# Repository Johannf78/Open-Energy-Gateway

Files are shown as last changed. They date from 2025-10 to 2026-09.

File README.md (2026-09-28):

# AmpX Open Energy Gateway





A comprehensive ESP32-based energy monitoring gateway that communicates with Meatrol Brand energy meters via Modbus protocols (RS485 and TCP/IP). The system collects data from up to 32 meters simultaneously, displays it through a web interface, and uploads measurements to a remote API for centralized monitoring.

**Buy ready-built hardware:** <a href="https://ampx.co/product/ampx-energy-gateway/" target="_blank" rel="noopener noreferrer">AmpX Energy Gateway</a> on ampx.co — DIN-rail unit with WiFi, RS485 or TCP/IP Modbus, and uploads to <a href="https://ampx.app" target="_blank" rel="noopener noreferrer">ampx.app</a>.

## 🌟 Features

### Core Capabilities
- **Multi-Protocol Support**: Compatible with both Modbus RS485 and Modbus TCP/IP communication
- **Multi-Meter Support**: Monitor up to 32 energy meters simultaneously
- **Real-Time Web Interface**: Live data display with WebSocket updates
- **API Integration**: Automatic data upload to AmpX Portal every 30 seconds
- **Auto-Discovery**: Automatic detection of connected meters
- **Dual Hardware Variants**: Separate builds for RS485 and TCP/IP configurations

### Hardware Integration
- **ESP32 Wroom 32U**: Main microcontroller platform
- **RS485 Interface**: MAX485 module for serial communication
- **Ethernet Interface**: W5500 Lite for TCP/IP communication
- **Status Indicators**: Four LEDs for system status monitoring
- **WiFi Support**: Wireless connectivity with WiFiManager

### Data Management
- **Real-Time Monitoring**: 3-second update intervals for web interface
- **Scheduled Uploads**: 30-second intervals for API data transmission
- **JSON Data Format**: Structured data exchange and storage
- **Meter Identification**: Unique serial number tracking for each meter

## ☁️ AmpX Energy Portal

View gateway and meter data in the cloud at <a href="https://ampx.app/" target="_blank" rel="noopener noreferrer">https://ampx.app/</a>.

The portal lets you manage gateways, inspect live and historical readings (voltage, current, power, and energy per phase), and export CSV for reporting. The firmware uploads a timestamped snapshot about every 30 seconds.

The portal can be **white-labelled** for your company or resellers (your branding, your domain). Data can also be **customised** and sent to **any portal or platform**, in **any format** you require. Contact AmpX if you need a branded instance or a custom integration.

## 🏗️ Architecture

```
┌─────────────────┐    ┌──────────────────┐    ┌─────────────────┐
│   Energy Meters │    │  AmpX Gateway    │    │   AmpX Portal   │
│                 │    │                  │    │                 │
│ Meatrol Meters  │◄──►│ ESP32 + Modbus   │◄──►│ Remote API      │
│ (RS485/TCP-IP)  │    │ Web Interface    │    │ Data Storage    │
│ Up to 32 units  │    │ Data Processing  │    │ Analytics       │
└─────────────────┘    └──────────────────┘    └─────────────────┘
```

## 📋 Hardware Requirements

### Base Components
- **ESP32 Wroom 32U** microcontroller
- **Power Supply**: 3.3V regulated power
- **Status LEDs**: 5x LEDs for system monitoring (Power, Meter, WiFi, Internet, Server)

### RS485 Configuration
- **MAX485 Interface Module**
- **RS485 Cable**: For meter communication
- **Pull-up/Pull-down Resistors**: 120Ω termination resistors

### TCP/IP Configuration
- **W5500 Lite Ethernet Module**
- **Ethernet Cable**: CAT5/CAT6 network connection
- **Network Switch/Router**: For meter and internet connectivity

## 🚀 Installation

### Prerequisites
- [Arduino IDE](https://www.arduino.cc/en/software) (recommended)
- In Arduino IDE, add this under `File -> Preferences -> Additional Board Manager URLs`:  
  `https://raw.githubusercontent.com/espressif/arduino-esp32/gh-pages/package_esp32_index.json`
  Then install `esp32` from `Tools -> Board -> Boards Manager`.
- ESP32 Board Package for Arduino IDE
- USB-to-UART driver for your ESP32 board (CP210x VCP driver): [Silicon Labs CP210x USB to UART Bridge VCP Drivers](https://www.silabs.com/developers/usb-to-uart-bridge-vcp-drivers)
- Required Arduino libraries (see Dependencies section)

### Quick Start

1. **Clone the Repository**
   ```bash
   git clone https://github.com/Johannf78/Open-Energy-Gateway.git
   cd Open-Energy-Gateway
   ```

2. **Open the Project**
   - **Arduino IDE** (recommended): Open `src/open_energy_gateway/open_energy_gateway.ino`
   - Alternative - PlatformIO: Open the project folder

3. **Configure Hardware Type**
   
   In `open_energy_gateway.ino`, set the communication type:
   ```cpp
   #define MODBUS_TYPE MODBUS_TYPE_RS485  // For RS485 version
   // OR
   #define MODBUS_TYPE MODBUS_TYPE_TCPIP  // For TCP/IP version
   ```

4. **Install USB Driver (Required)**
   - Most ESP32 development boards use a CP210x USB-to-UART bridge chip
   - Install the CP210x VCP driver from Silicon Labs:  
     [https://www.silabs.com/developers/usb-to-uart-bridge-vcp-drivers](https://www.silabs.com/developers/usb-to-uart-bridge-vcp-drivers)
   - On the Silicon Labs download list (Windows), select **CP210x Windows Drivers**
   - Reconnect the board after driver installation so the serial COM port is detected

5. **Upload to ESP32**
   - Connect your ESP32 via USB
   - Select the correct board and port
   - Compile and upload the code

### Dependencies

The following libraries are required:
```cpp
#include <WiFi.h>              // ESP32 built-in WiFi
#include <WebServer.h>         // ESP32 built-in web server
#include <WebSocketsServer.h>  // Real-time updates (by Markus Sattler)
#include <ArduinoJson.h>       // JSON processing (by Benoit Blanchon)
#include <HTTPClient.h>        // ESP32 built-in HTTP client
#include <WiFiManager.h>       // WiFi configuration (by tzapu)
#include <Preferences.h>       // ESP32 built-in NVS storage
#include <HardwareSerial.h>    // ESP32 built-in serial communication
#include <time.h>              // ESP32 built-in time functions
```

### Custom Libraries (Required)
The project requires custom AmpX Modbus libraries available at:
**Repository**: [https://github.com/Johannf78/AmpXModbus](https://github.com/Johannf78/AmpXModbus)

- **For RS485**: `ampx_modbus_rs485.h` 
- **For TCP/IP**: `ampx_modbus_tcpip.h`

**Installation**:
1. Clone or download the AmpXModbus repository
2. Copy the library folders to your Arduino libraries directory:
   `Documents/Arduino/libraries/`

## 🔧 Configuration

### WiFi Setup
On first boot, the device creates a WiFi access point:
- **SSID**: `AmpX-Energy-Gateway-AP`
- **Password**: None (open network)
- Connect and configure your WiFi credentials through the captive portal

### Meter Configuration
Meters are automatically discovered during startup. The system supports:
- **Meter Addresses**: 1-32 (configurable)
- **Baud Rate**: 9600 (RS485)
- **Data Bits**: 8
- **Parity**: None
- **Stop Bits**: 1

### API Configuration
The system supports dual API endpoints (configurable in `open_energy_gateway.ino`):
```cpp
// Local: LAN IP of the PC running XAMPP (port 80). Update when the PC IP changes.
const char* ampxportal_server_local = "http://192.168.2.120/api/v3/";
const char* ampxportal_server_live = "https://ampx.app/api/v3/";
const char* ampxportal_api_key = "...";  // must match AMPX_API_KEY in api/config/config.php
#define USE_LOCAL_SERVER false  // true = LAN XAMPP /api/v3/; false = live /api/v3/
```

Every upload sends header `X-AmpX-Api-Key` (firmware **1.0.3+**). Full API docs: `ampx.app/api/README.md`.

**Breaking changes:** If the portal/API contract changes so older flashed gateways fail, bump `FIRMWARE_VERSION` in the same change and publish OTA before (or with) the live API cutover. The API key requirement is one such break (pre-1.0.3 → 401).

**Local development stack (verified July–August 2026):**
- API: XAMPP at `D:\xampp\htdocs\ampx.app\api\` — firmware posts `POST /api/v3/` (Cloud). Header `X-AmpX-Api-Key` (see that folder’s `README.md`)
- Portal UI: http://ampx-app.local/ (WordPress vhost; not the public Cloudflare `ampx.app` host)
- InfluxDB (legacy v2 path): `influxdb2.ampx.app` via `POST /api/v2/`
- InfluxDB (portal + v3): managed **Cloud Serverless** — account AmpX / org **Energy Gateway** — host `https://eu-central-1-1.aws.cloud2.influxdata.com` (AWS Frankfurt); see `ampx.app/api/README.md`
- Postman: `http://ampx-app.local/api/v2/` or `http://127.0.0.1/api/v2/` — enable header `X-AmpX-Api-Key`
- ESP must reach the PC on TCP **80**; Windows Wi‑Fi profile should be **Private** with Apache firewall allow rules
- Do not use port **8080** unless a separate Docker API is running

**Live stack (verified August 2026 Cloud cutover):**
- API: `https://ampx.app/api/v3/` — `#define USE_LOCAL_SERVER false` (v2 still on Influx 2 until sunset)
- Portal UI: https://ampx.app/ → Meters → gateway → View Data (Cloud / InfluxQL, plugin 1.1.5)
- WordPress `wp-config.php` `AMPX_INFLUXDB_*` → Cloud Serverless; **ORG** = `Energy Gateway` (not AmpX)
- After editing live `wp-config.php` on Hetzner: flush PHP OPcache
- Create/assign the gateway in WP Admin; Influx data alone does not register it in the portal list
- OTA: live `version.json` is **1.0.9** (v2). Next publish is **1.1.1**. Do not publish 1.0.9.

## 💻 Usage

### Web Interface
1. Connect to your local network
2. Find the ESP32's IP address (displayed on serial monitor)
3. Open `http://[ESP32_IP_ADDRESS]` in your browser
4. View real-time meter data in tabular format

### Data Format
The system collects and transmits:
- **Meter Serial Numbers**: Unique identification
- **Energy Measurements**: kWh, kW, Voltage, Current
- **Timestamps**: Measurement time
- **Status Information**: Connection and error states

### API Integration
Data is automatically uploaded to the AmpX Portal every 30 seconds in JSON format:
```json
{
  "gateway_id": "100001",
  "meter_id": "1",
  "serial_number": "12345678",
  "timestamp": "2024-01-15T10:30:00Z",
  "values": {
    "serial": "12345678",
    "voltage_L1": "230.1",
    "current_L1": "24.6",
    "active_power_tot": "5.67",
    "active_energy_imported_tot": "1234.56"
  }
}
```

## 🛠️ Development

### Project Structure
```
Open-Energy-Gateway/
├── src/
│   └── open_energy_gateway/
│       ├── open_energy_gateway.ino       # Main application
│       ├── functions.ino                 # NVS utilities
│       ├── functions_modbus.ino          # Modbus communication
│       ├── functions_web.ino             # Web interface & WebSocket
│       ├── functions_wifi.ino            # WiFi management
│       ├── functions_ethernet.ino        # Ethernet initialization
│       ├── functions_meter.ino           # Meter register definitions
│       ├── functions_api.ino             # API communication
│       ├── functions_ntp.ino             # Time synchronization
│       ├── functions_ota.ino             # HTTP pull OTA (Admin)
│       ├── meter_registers.h             # Register definitions
│       ├── webpage.h                     # HTML templates
│       ├── web_admin.h                   # Admin interface
│       ├── web_settings.h                # Settings page
│       ├── data/                         # Web assets (future SPIFFS option)
│       │   ├── index.html
│       │   ├── settings.html
│       │   ├── admin.html
│       │   └── meter_registers_meatrol.json
│       └── tools/                        # SPIFFS tools (future use)
│           ├── create_spiffs.bat
│           ├── upload_spiffs.bat
│           └── spiffsgen.py
├── memory-bank/                          # Project documentation
├── Documentation/                        # User documentation
└── README.md
```

### Building Different Variants
- **RS485 Version**: Set `MODBUS_TYPE_RS485`
- **TCP/IP Version**: Set `MODBUS_TYPE_TCPIP`

### Debugging
Enable debug output by defining:
```cpp
#define DEBUG 1
```

### Web Interface Implementation
Currently, the web interface is implemented using header files containing HTML templates:

- **webpage.h**: Main dashboard HTML template
- **web_settings.h**: Settings page HTML template  
- **web_admin.h**: Admin page HTML template

The templates use string replacement for dynamic content (meter serial numbers, values, etc.).

### Future SPIFFS Option
The project includes infrastructure for future SPIFFS implementation:

1. **SPIFFS Tools Available** (not currently used):
   ```bash
   cd src/open_energy_gateway/tools
   create_spiffs.bat  # Future: Create SPIFFS image
   upload_spiffs.bat  # Future: Upload to ESP32
   ```

2. **Web Assets Ready** in `data/` folder for future SPIFFS deployment

### Current Limitations
- **Active Meters**: Currently configured for 5 meters (backend expandable; HTML rows needed beyond that)
- **Server URLs**: API and OTA hosts (`ampxportal_server_local` / `_live`, `USE_LOCAL_SERVER`, firmware URLs) require a firmware rebuild
- **Gateway ID**: Changeable from Admin; stored in NVS (`DEFAULT_GATEWAY_ID` is first-boot only)
- **OTA Updates**: Admin HTTP pull from `https://ampx.app/firmware/` (Check + Update); first flash USB with 8MB dual-OTA partitions; sketch **1.1.1** (live `/api/v3/`); next OTA publish **1.1.1** — do not publish **1.0.9** (still v2)
- **Admin Interface**: Gateway reboot (LEDs off first) + OTA + Clear WiFi (ship-mode); Gateway ID change with password

### Shipping a gateway
1. Set Gateway ID on Admin (if not already assigned in the portal).
2. Open **Admin → Clear WiFi (Ship Mode)**, enter the admin password, confirm.
3. Confirm the open AP `energy-gateway-{ID}` appears (no workshop SSID).
4. Box the unit. At the site, the customer joins that AP, opens **http://192.168.4.1**, saves their WiFi, then opens `http://energy-gateway-{ID}.local` or the IP from their router.
5. Do not leave workshop WiFi stored on a unit that will be shipped.

## 🔍 Troubleshooting

### Common Issues

**No Meter Communication**
- Check wiring connections
- Verify meter addresses (1-32)
- Ensure proper termination resistors (RS485)
- Check network connectivity (TCP/IP)

**Web Interface Not Loading**
- Verify ESP32 is connected to WiFi
- Check IP address in serial monitor
- Ensure port 80 is not blocked

**Web UI Stuck on “Connecting…” (WebSocket)**

The page is served over HTTP (port 80). **Connection status: Connecting…** means the browser is waiting for the WebSocket on **port 81** (`ws://hostname:81/`). The HTTP page can load while the WebSocket is still down.

**Cause:** Modbus reads block the ESP32. The WebSocket on port 81 is only accepted when `webSocket.loop()` runs. On TCP, each register used to open and close port 502, so the first page could sit on Connecting for up to about 40 seconds.

**Current pattern (Sep 2026):** one Modbus TCP socket for the whole sweep, closed once at the end of `handlePowerMeter()`. `server.handleClient()` and `webSocket.loop()` run before every register read, and `handleWebSocket()` sends the JSON once after the sweep. Bench measurement before a leftover 100 ms pause was removed: about 5 seconds. There is no per-register `delay(100)`; `modbus_read_response()` already waits up to 2 seconds for the frame.

Also keep `server.handleClient()` / `webSocket.loop()` at the end of `loop()`. Do not call `reconnectMeter()` / `initEthernet()` from the 1-second meter path (`initEthernet()` waits 2 seconds and freezes the page).

**Boot delay (separate from the meter sweep):** Before `loop()` runs, `setup()` may wait on NTP (up to about 15 seconds). The web server does not handle clients until `setup()` finishes.

**Cannot Connect to Setup Hotspot (Windows)**

On first boot (or when no WiFi credentials are saved), the gateway creates an open access point named `energy-gateway-{GATEWAY_ID}` (for example `energy-gateway-100001`). Connect to this network and open **http://192.168.4.1** to configure WiFi.

**Problem:** Windows shows as connected to the hotspot, but the PC does not receive an IP address (often `169.254.x.x` instead of `192.168.4.x`), so the setup page cannot be opened. The Windows Settings UI may still show “IP assignment: Automatic (DHCP)” even when DHCP is not actually active on the adapter.

**Solution:**
1. Confirm in Command Prompt with `ipconfig /all` that the Wi‑Fi adapter shows **DHCP Enabled: Yes**.
2. If it shows **No**, enable DHCP from an elevated Command Prompt or PowerShell:
   ```
   netsh interface ip set address name="WiFi 3" dhcp
   netsh interface ip set dns name="WiFi 3" dhcp
   ```
   Replace `WiFi 3` with your adapter name from `ipconfig` if different.
3. Disconnect and reconnect to the gateway hotspot, then check that you have an address such as `192.168.4.2` and gateway `192.168.4.1`.
4. Open **http://192.168.4.1** in a browser.

**Workaround:** If DHCP still fails, set a temporary static IP on the Wi‑Fi adapter: IP `192.168.4.10`, subnet mask `255.255.255.0`, gateway `192.168.4.1`.

**API Upload Failures**
- Serial success looks like: `HTTP Response Code: 201` and `Data stored successfully`
- HTTP **401**: `ampxportal_api_key` must match `AMPX_API_KEY` in `api/config/config.php` (local already enforces this)
- `connection refused` (-1) to the PC IP: check Windows Firewall / Wi‑Fi **Private** profile; Apache must accept LAN inbound on port 80 (not only localhost)
- Confirm `ampxportal_server_local` matches the PC’s current LAN IP and uses `/api/v3/` on port 80 (local Cloud path)
- Confirm InfluxDB is healthy (`https://influxdb2.ampx.app/health`) — API returns 500 if storage fails
- View data (local): http://ampx-app.local/ → Meters → gateway → View Data
- View data (live): https://ampx.app/ → Meters → gateway → View Data (needs WP gateway assignment + `AMPX_INFLUXDB_*` in live `wp-config.php`)
- Misleading firmware message: “No internet connection” on connection-refused may mean LAN blocked, not WAN down

**Admin OTA reboot / Checking… stuck**
- Serial `rst:0x8 (TG1WDT_SYS_RESET)` after `Fetching firmware manifest:` = old firmware (≤1.0.5) putting `WiFiClientSecure` on the `loop()` stack — USB-flash or OTA **1.0.7+**
- Opening Admin must not fetch; only **Check for update** starts HTTPS
- Serial Monitor baud is **115200**
- Live files: `https://ampx.app/firmware/version.json` and the `.bin` must both be published and versions aligned

**Live portal “critical error” on Meters**
- Check Debug Log Manager log (path in `WP_DEBUG_LOG`), not only Apache `www_logs`
- Common cause: missing `AMPX_INFLUXDB_*` constants in live `wp-config.php`
- If constants were just added and error persists: flush PHP OPcache

**NTP `TIMEOUT!` on boot**
- `initNTP()` waits up to a max (currently ~15s) and exits early on success; increase the timeout if sync still fails
- Check router/firewall allows outbound NTP (UDP/123)

### Status LED Indicators
- **LED 1 (Power - Pin 12)**: System power status
- **LED 2 (Meter - Pin 14)**: Meter communication status  
- **LED 3 (WiFi - Pin 27)**: WiFi connection status
- **LED 4 (Internet - Pin 26)**: Internet connectivity status
- **LED 5 (Server - Pin 25)**: API server communication status

## 🤝 Contributing

We welcome contributions! Please follow these steps:

1. Fork the repository
2. Create a feature branch (`git checkout -b feature/amazing-feature`)
3. Commit your changes (`git commit -m 'Add amazing feature'`)
4. Push to the branch (`git push origin feature/amazing-feature`)
5. Open a Pull Request

### Development Guidelines
- Follow Arduino coding standards
- Test with actual hardware when possible
- Update documentation for new features
- Maintain backwards compatibility

## 📄 License

This project is licensed under the MIT License - see the [LICENSE](LICENSE) file for details.

## 🏢 Commercial Use

This project is designed for industrial and commercial energy monitoring applications:
- **Manufacturing Facilities**: Multi-zone energy monitoring
- **Commercial Buildings**: Tenant energy tracking
- **Energy Auditing**: Standardized data collection
- **Remote Monitoring**: Centralized meter management

## 📞 Support

- **Contact AmpX**: <a href="https://ampx.co/contact/" target="_blank" rel="noopener noreferrer">ampx.co/contact</a> — product questions, quotes, and commercial support
- **Issues**: [GitHub Issues](https://github.com/Johannf78/Open-Energy-Gateway/issues)
- **Documentation**: See `memory-bank/` folder for detailed technical documentation
- **Hardware Support**: Compatible with Meatrol Brand energy meters

## 🙏 Acknowledgments

- ESP32 Community for excellent documentation and libraries
- Modbus community for protocol specifications
- Contributors to the WebSocket and WiFiManager libraries

---

**Built with ❤️ for the energy monitoring community**

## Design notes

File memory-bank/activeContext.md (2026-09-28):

# Active Context - AmpX Open Energy Gateway

## Current Focus
**Sep 28, 2026 — Live OTA catalog is 1.2.1 (single `{version,url}`).** Sketch `FIRMWARE_VERSION` is **1.2.1**. `https://ampx.app/firmware/version.json` is **1.2.1**. The downloaded `ampx_open_energy_gateway.bin` is **1,335,296** bytes and contains the ASCII string **1.2.1** (not 1.0.9). Cloudflare cache rule **Bypass firmware OTA** is **Active**: URI Path starts with `/firmware/` → Bypass cache.

**Not confirmed after that rule:** Admin on gateway **100007** still needs a Check + Update so **Current firmware version** reads **1.2.1**. Two earlier OTAs the same morning reported `OK: update applied (1.2.1)` and then booted **1.0.9**. That status line appends the **manifest** version (`saveOtaStatus` in `doOTAUpdate()`), not the string compiled into the image. Cloudflare was still serving the old `.bin`. Do not treat the field unit as 1.2.1 until Admin says so.

**100007** is Modbus **TCP/IP** (W5500), not RS485. ME537 serial **3423875005**. On 26 Sep, with voltage and current coils connected, gateway and live portal agreed (about 237–240 V; L2 idle; L1/L3 power and imported energy added up). `detectNumberOfMeters()` used to print RS485 always (`if (MODBUS_TYPE_RS485)` is `if (1)`). It now compares `MODBUS_TYPE == MODBUS_TYPE_RS485`.

**Register map** in `meter_registers.h` (this is what `setupMeterRegisters()` loads; `data/meter_registers_meatrol.json` is a copy):

| Key | Address | Words | Type |
|-----|---|---|---|
| `frequency` | 1024 | 2 | float |
| `power_factor_L1` | 1052 | 2 | float |
| `power_factor_L2` | 1054 | 2 | float |
| `power_factor_L3` | 1056 | 2 | float |

Do **not** send `power_factor_tot` (register 1058). API v3 allows only `mN_power_factor_L[1-3]`. One invalid key returns **400** for the whole post. The portal has no total power-factor column. `postToAmpXPortal2()` already forwards every `mN_` key. Local `/meters` still has **no** `meter_frequency` / `meter_power_factor_L*` cells, so those values do not show there. The unit `if` in `web_meters.h` checks `power_factor` before `power` (otherwise the key is labelled kW).

**Sep 28, 2026 — TCP Meter Details connects in about 5 seconds (was up to ~40).**

One Modbus TCP socket stays open for the whole register sweep, and the WebSocket is serviced between registers. Measured on the bench before the per-register `delay(100)` was removed: page status green and values up in ~5 s. That pause is now gone (`modbus_read_response()` already waits up to 2 s), which should take about another 2 s off; not re-timed yet.

**Library** `ampx_modbus_tcpip.cpp` (Arduino libraries, not the sketch tree):
- `modbus_test_connection()` connects to port 502 and **leaves the socket open** (already open → return true). It is still a TCP open, not a Modbus PDU.
- `modbus_send_request()` reuses that socket and connects only if it dropped.
- `modbus_read_response()` does **not** `stop()` on a full reply. It closes on a short frame (`bytesRead < 9`) or when the header arrived without the register bytes.
- No `delay(100)` before the read.

**Sketch** `functions_meter.ino`:
- Inside the register loop, before each read: `server.handleClient()` + `webSocket.loop()`. Do not call `handleWebSocket()` there; the JSON is still broadcast once after the sweep.
- End of `handlePowerMeter()`, TCP only: `modbusClient.stop()` once.
- `reconnectMeter()` stays **unhooked**. `initEthernet()` has `delay(2000)` and must not run on the 1 s path.

UI copy in `web_home.h`, `web_meters.h`, and `web_settings.h` now says the initial connection usually takes a few seconds (was “up to 30 seconds”).

**Sep 6, 2026 — ESP32-S3 bench port: WORKING on a stock DevKitC-1U.** Both sketches compile, flash and run; W5500 detected; WiFi AP up. Only the meter link is untested.

### Next session — start here
1. Set the meter's Ethernet to `192.168.1.55` (gateway `192.168.1.1`, mask `255.255.255.0`, Modbus-TCP enabled, port 502) so it matches the firmware defaults — the User Manual V1.0 still documents the old `192.168.2.122` pair, so **either the meter or the manual needs changing**; decide which and make them agree.
2. LAN cable W5500 ↔ meter. Expect `Link is ON`, Modbus test pass, METER LED on.
3. Then: WiFi provisioning via the AP, API post to `ampx.app/api/v3/`, and finally OTA with `CHIP_OTA_KEY = esp32s3`.
4. Consider soldering headers for the four SPI lines — dupont on breadboard caused two false "no hardware" failures today.

**Sep 11, 2026 — hardware V3 decisions that need firmware work (not yet written):**
- **Reset button on GPIO 13**, front panel, recessed pinhole. Function: **hold 3 s → clear saved WiFi credentials → restart → WiFiManager falls into AP mode** (`clearStoredWifi()` + `ESP.restart()` already exist; currently only reachable from the admin web page — which is exactly what a customer cannot reach after changing their router). Short press: reboot, or nothing — undecided.
- GPIO 13 chosen because WROVER-IE has no GPIO 16/17; 5/18/19/23 are the W5500; 12/14/25/26/27 the LEDs; 0/2/15 are strapping (GPIO 0 low at boot = bootloader mode); 21/22 kept for I²C; 32/33 kept for the RS485 variant.
- Hardware: 10 kΩ pull-up + 100 nF on the **main** board, switch to GND on the front board, `INPUT_PULLUP` also set in firmware so the pin is defined when the ribbon is unplugged.
- **Firmware still to write:** button handler with (a) LED feedback — flash all five LEDs at the 3 s threshold so the user knows to release; (b) blink the WiFi LED in AP mode to distinguish "waiting for setup" from "not working"; (c) **stuck-button guards — ignore the button for the first 2 s after boot and require a clean high→low→high transition**, otherwise a pinched ribbon wipes credentials on every boot and strands the unit in AP mode permanently.
- Also noted: the 24 h auto-reboot in `loop()` is still commented out (`//ESP.restart();`).
- Front/back boards now joined by one 2×4 IDC ribbon carrying 5 LEDs + button + V + GND. Base board is USB-powered; the front status board is fed from it.
- Docs: `AmpX Products\AmpX Energy Gateway\AmpX Energy Gateway - Hardware Notes and connections.md` and `...- Prototype Build 5 - Procurement Status.md`.

### Detail
- `open_energy_gateway.ino`: new **Board pin map** block (`#if CONFIG_IDF_TARGET_ESP32S3 … #else` classic ESP32). ESP32 map unchanged; LED/ETH/RS485 defines moved out of the `MODBUS_TYPE` blocks into it.
- S3 map: LEDs 4/5/6/7/15 · W5500 SCK 12, MISO 13, MOSI 11, CS 10, RST 14 (optional) · RS485 DE 16, RX 18, TX 17 (reserved).
- `functions_ethernet.ino`: `SPI.begin(SCK, MISO, MOSI, -1)` explicit before `Ethernet.init()`; optional `ETH_SPI_RST_PIN` pulse.
- New `src/TestS3Bringup/TestS3Bringup.ino` — flash first: chip/PSRAM report, LED walk, W5500 detect, link + port 502.
- IDE: ESP32S3 Dev Module, CDC on boot **Disabled** (UART socket), OPI PSRAM, flash size per module, custom `partitions.csv`.
- **Bench result 6 Sep:** `TestS3Bringup` compiled and ran on an ESP32-S3-DevKitC-1U **N8R8** (8 MB QIO flash, 8 MB OPI PSRAM, core 3.3.x / IDF 5.5.5). LEDs 4/5/6/7/15 OK, **W5500 detected** on FSPI 12/13/11/10, IP 192.168.1.50. First failure was the four SPI wires one header pin too high (CS on 9) — count from bottom GND: 13 orange, 12 yellow, 11 blue, 10 green.
- **Main firmware runs on S3 (6 Sep):** `open_energy_gateway.ino` compiled and ran first time on the S3 — `ampx_modbus_tcpip` built without changes, NVS + gateway ID OK, **W5500 detected**, WiFiManager AP `energy-gateway-100001` at 192.168.4.1. Only `Link is OFF` (no LAN cable yet).
- Two intermittent "No Ethernet hardware detected" failures during bring-up were both **loose dupont contacts** on the breadboard, not firmware. If it ever recurs: power-cycle fully (W5500 keeps state across an ESP32 reset), then re-flash `TestS3Bringup` to split hardware from firmware.
- `ETH_SPI_RST_PIN` is now commented out in the pin map — defining it pulses a pin that is not wired. Uncomment only if RST is physically connected.
- **Still unverified on S3:** meter read over Modbus TCP; API post; OTA. `CHIP_OTA_KEY` already yields `esp32s3` — never publish an S3 .bin at the single legacy URL.
- Hardware gap: V2 bottom PCB footprint is DevKitC-32U (2×19); S3-DevKitC-1U is 2×22 → new footprint + bottom board respin before enclosure fit. **Open decision:** does production go on a DevKitC-1U carrier or the custom S3 board (LCSC parts bought Dec 2025)? That choice, plus "freeze the ESP32 fleet at date X vs. maintain two families", is worth settling before the respin — it is an exit/sellability question, not just an engineering one.
- Mirror of the pin table: `AmpX Products\AmpX Energy Gateway\AmpX Energy Gateway - Hardware Notes and connections.md`.

**Aug 23, 2026:** Multi-chip OTA **designed, not shipped**. `fetchFirmwareManifest()` still reads only top-level `version` and `url`. **Sep 28:** live catalog was published as single-url **1.2.1** anyway (that is what this firmware understands). Chip-aware `targets.esp32` is still future work. Never put an S3 `.bin` at `firmware/ampx_open_energy_gateway.bin`. Do **not** put **1.0.9** back at that URL (it posts `/api/v2/`).

Plan (pick up later): `memory-bank/plans/2026-08-23-multi-chip-ota.md`  
Spec: `ampx.app/docs/superpowers/specs/2026-08-23-multi-chip-ota-design.md`

Sketch `FIRMWARE_VERSION` is **"1.2.1"** and `CHIP_OTA_KEY`; `fetchFirmwareManifest()` still uses top-level `version`/`url` and `firmwareURL` fallback. `setup()` prints the version on the serial monitor after the port is ready. Live `version.json` matches **1.2.1** (published 28 Sep 2026).

Also today: TCP/IP meter connection test verified. Cable/link is in `functions_meter.ino` (`meterTransportReady` / `Ethernet.linkStatus() == LinkOFF`), not in `ampx_modbus_tcpip`. `loop()` calls `serviceMeters()`.

**Ready for next session:**
- Confirm gateway **100007** Admin shows **1.2.1** after Check + Update (catalog and `.bin` are already 1.2.1; Cloudflare `/firmware/` bypass is on).
- Confirm the next portal row for SN **3423875005** has frequency near 50 and power factor on L1–L3. Portal headings still say **W** and **Wh** while the gateway sends **kW** and **kWh**.
- Add `meter_frequency` and `meter_power_factor_L1`–`L3` cells on the local meters page if those values should show there.
- Chip-aware OTA (`targets`) is still not parsed. Do not publish an S3 image at the legacy `.bin` URL. Do not publish **1.0.9**.
- Optional: Modbus probe (registers 70–71) in TCP `modbus_test_connection()`; RS485 test is still `return true`.

Previous: multi-chip OTA spec (23 Aug); TCP/IP connection test; live Cloud cutover (1.1.1 USB); firmware local v3; portal InfluxQL; API v3.

## Recent Major Achievements

### TCP/IP meter connection test (August 2026) — Session 19
**Symptom:** TCP `modbus_test_connection()` looked always-positive. It is **not** the RS485 stub (`return true`). As of this session it was `EthernetClient.connect(meter_ip, 502)` then `stop()` — a TCP open, not a Modbus PDU. **Sep 28:** the `stop()` was removed so the sweep can reuse the socket (see top). Putting `Ethernet.linkStatus()` in `ampx_modbus_tcpip.cpp` failed in the IDE (`LinkOFF` / `Ethernet` undeclared) because that `.cpp` is parsed without Arduino Ethernet includes.

**Fix (sketch, verified 23 Aug 2026):**
- `meterTransportReady()` — TCP/IP only: `Ethernet.linkStatus() == LinkOFF` → false; RS485 always true
- `serviceMeters()` — early returns: no link → LED 2 off, skip Modbus and `initEthernet()`; test fail → LED 2 off, `reconnectMeter()`; success → LED 2 on, `readNextMeter()`
- `loop()` interval block only calls `serviceMeters()`
- Do **not** name it `handleMeters()` — that is the `/meters` HTTP handler

**Not done:** Modbus register probe in the TCP library; RS485 `modbus_test_connection()` stub.

### Live Cloud / API v3 cutover (August 2026) — Session 18
**Objective:** Point live Hetzner + firmware + portal at Cloud Serverless. Keep `/api/v2/` until the fleet is on 1.1.1.

**Deployed:**
- Live `wp-config.php` `AMPX_INFLUXDB_*` → Cloud host / Cloud token / org **Energy Gateway** / bucket `energy_metrics` (not account name AmpX, not Influx 2 org `ampx`)
- Plugin **1.1.5** InfluxQL; flush OPcache after wp-config
- Live `/api/v3/` (GET **405** `api_version` 3.0; no key **401**; keyed POST **201**; test serial `live_verify_20260822` landed in Cloud)
- Sketch **1.1.1**: both URLs `/api/v3/`; `USE_LOCAL_SERVER false`
- Meter Data page: deleted Kadence **Example Meter Info** (100001 / Test / 2724193001)

**Verified live UI (admin, 22 Aug):** 100007 / 3423875005 — 377 then 395 readings, newest ~14:17 UTC, oldest 10:52 UTC (first Cloud point). Voltages mostly 0 (meter read, not API).

**Not done:** OTA publish 1.1.1; theme 1.0.9; sunset v2; other field units still on v2 are invisible on live portal.

**Org naming:** Cloud **account** = AmpX; Cloud **organization** = Energy Gateway (ID `86a141bfd8d7f66a`). One-org quota — do not create a second org.

### Portal InfluxQL / Cloud reads (August 2026)
**Objective:** Meters / View Data / CSV read Cloud Serverless instead of Flux on `influxdb2.ampx.app`.

**Implementation:**
- `AMPX_Portal_InfluxDB_Detailed` uses `GET /query?db=energy_metrics` (InfluxQL) and parses wide JSON rows
- `wp-config.php` `AMPX_INFLUXDB_*` → Cloud host / `INFLUXDB_CLOUD_TOKEN` / org Energy Gateway (local + live)
- Plugin **1.1.5**

**Verified CLI (22 Aug 2026, local):**
- `100001` / `SN-1234567890`: 2 readings
- `100008` / `v3_plan_test`: 1 reading

**Verified live UI:** 100007 / 3423875005 Cloud table (Session 18)

### API v3 Cloud Serverless writes (August 2026)
**Objective:** Isolated `/api/v3/` clone of v2 that writes `meter_readings_detailed` to Cloud Serverless. Keep v2 on `influxdb2.ampx.app`.

**Implementation:**
- `api/v3/index.php`, `src/DataValidator.php`, `src/InfluxDBHandlerDetailed.php` (`AmpX\ApiV3`)
- Same JSON + `X-AmpX-Api-Key`; `api_version` **3.0**
- Write URL uses `INFLUXDB_CLOUD_*` with **org ID**
- Plan: `ampx.app/docs/superpowers/plans/2026-08-22-api-v3-cloud-serverless.md`

**Verified local + live (22 Aug 2026):** GET **405**; no/wrong key **401**; valid POST **201** `"api_version":"3.0"`

### Firmware `/api/v3/` (August 2026)
**1.1.0** local USB; **1.1.1** live USB on **100007**. Plan: `ampx.app/docs/superpowers/plans/2026-08-22-firmware-api-v3.md` (local slice) and `2026-08-22-live-cloud-cutover.md`.

**Compile note (ESP32 3.3.11 Windows):** stub `OpenThread/bits/align.h` → `#include_next`; merge-bin `--pad-to-size 8MB` can `MemoryError` (app `.bin` still built).

### Ship-mode / Clear WiFi (August 2026) — firmware 1.0.9
**Objective:** Before boxing a unit, erase workshop WiFi so first boot at the customer site starts WiFiManager AP mode (open AP `energy-gateway-{GATEWAY_ID}`).

**Implementation:**
- Admin card **Clear WiFi (Ship Mode)** → `POST /clear_wifi` with shared `ADMIN_PASSWORD` (same secret as Gateway ID)
- `clearStoredWifi()` calls `WiFiManager.resetSettings()` — do **not** call this from `initWiFi()` (that would wipe every boot)
- Erases WiFi credentials only; Gateway ID, meter names, and OTA NVS stay
- Status page uses ASCII hyphen (`WiFi Cleared - Rebooting`); standalone HTML has no `charset`, so a UTF-8 em dash showed as `â€"`
- All five status LEDs `LOW` before `ESP.restart()` on Clear WiFi **and** Admin Reboot (`handleRebootGateway`)
- WiFiManager `/wifisave` copy via `setCustomHeadElement()`: next steps are `http://energy-gateway-{ID}.local` or the IP from the customer router; `setCustomHeadElement` stores a pointer — keep the `String` alive until `autoConnect()` returns

**Verified:** Gateway **100007** — wrong password 403; correct password reboots into AP; save page at `192.168.4.1/wifisave`.

**Ops:** Live OTA still **1.0.7** until 1.0.9 `.bin` + `version.json` are deployed together.

### Live HTTPS OTA + WDT fix (August 2026) — firmware 1.0.7
**Symptoms (on 1.0.4/1.0.5):** Admin stuck on **Checking…**; opening Admin or **Check for update** rebooted. Serial: `Fetching firmware manifest: https://ampx.app/firmware/version.json` then `rst:0x8 (TG1WDT_SYS_RESET)` (~3s), no Guru Meditation.

**Root cause:** Local `WiFiClientSecure` on the Arduino `loop()` stack (default **8KB**) during TLS handshake. IWDT stage-2 hard-reset when the panic handler could not run. Opening Admin also auto-called `requestOtaManifestCheck()`, so merely loading `/admin` started HTTPS. Version compare was string equality, so device **1.0.6** vs server **1.0.5** showed “Update available”.

**Fix (1.0.6/1.0.7):**
- `SET_LOOP_TASK_STACK_SIZE(16384)` in `open_energy_gateway.ino`
- Static `otaTlsClient` / `otaPlainClient` in `functions_ota.ino` (BSS, not stack)
- Admin: **Check for update** → `GET /ota_status?refresh=1`; page load does **not** start TLS; no 5‑minute auto-refresh
- `isNewerVersion()` numeric `major.minor.patch`; Update Firmware only if server **>** device (`doOTAUpdate` / `handleUpdate` same guard)

**Verified Aug 18, 2026** (gateway **100008**):
- Check: `Manifest HTTP 200` / `OTA manifest OK: 1.0.5` without reboot
- Live OTA install: **OK: update applied (1.0.7)**; after Check, Current = Available **1.0.7**, status **Up to date**, Update disabled
- Live files: `https://ampx.app/firmware/version.json` + `.bin`

Do **not** ship **1.0.3** (reboot loop), **1.0.4/1.0.5** (Admin/Check WDT), or put `WiFiClientSecure` as a local in `loop()`. **1.0.7** was the live HTTPS OTA baseline; current sketch is **1.0.9** (ship-mode).

### OTA FreeRTOS reboot-loop fix (August 2026) — firmware 1.0.4
**Symptom**: After flashing **1.0.3**, gateway reboot-looped a few seconds after boot. Serial showed `EXCCAUSE: 0x02` (LoadProhibited), `Backtrace: … |<-CORRUPTED`. Gateway ID (e.g. 100008) loaded from NVS, then panic.

**Root cause**: 1.0.3 ran `otaManifestTask` on a FreeRTOS side task (core 0) that immediately fetched the **HTTPS** manifest (`USE_LOCAL_SERVER false` → `https://ampx.app/firmware/version.json`). Unsafe combo: `WiFiClientSecure` / `HTTPClient` off the Arduino loop task + Arduino `String` fields in `otaStatusCache` shared with WebServer handlers on core 1 → heap/stack corruption.

**Fix (1.0.4)**:
- Removed `xTaskCreatePinnedToCore(otaManifestTask, …)`
- `serviceOtaManifestCheck()` runs only from `loop()` (same core as WebServer)
- No boot-time auto-fetch: `otaManifestCheckRequested` starts `false`; first check only when Admin opens (`requestOtaManifestCheck`); 5‑minute refresh only after a prior check
- Handlers still must not call outbound `HTTPClient` (cache + `/ota_status` poll only)

**Verified**: USB flash 1.0.4; stable run past WiFi/meters (Aug 17, 2026). Do **not** put `WiFiClientSecure` or shared Arduino `String` caches on a FreeRTOS side task again.

### InfluxDB Cloud Serverless account (August 2026)
**Decision**: Use **managed Cloud Serverless** (not self-hosted Influx on Hetzner). Path later: Serverless → Cloud Dedicated if quotas/isolation require it. **InfluxDB 3 Cloud** (managed Enterprise) is early-access / separate product — not used yet.

**Org details** (no secrets in docs):
| Field | Value |
|---|---|
| Account | AmpX |
| Organization | Energy Gateway |
| Org ID | `86a141bfd8d7f66a` |
| Product | InfluxDB Cloud Serverless (v3 storage engine) |
| Provider / region | AWS `eu-central-1` (EU Frankfurt) |
| Cluster URL | `https://eu-central-1-1.aws.cloud2.influxdata.com` |
| Bucket | `energy_metrics` (ID `43bdc9cfa0531940`, retention **30 days**, schema Implicit) |
| Signup email | Company AmpX address (not personal Gmail) |

**Ops notes**:
- API token **AmpXGateway** created; value stored in local `api/config/config.php` as `INFLUXDB_CLOUD_*` (not in README/git docs). Rotate if exposed outside trusted channels.
- Writes: v1/v2-compatible line protocol; queries: **SQL** / InfluxQL (Flux not the target)
- Rough Serverless cost at 200 gateways × 30s uploads is material; prefer longer intervals (e.g. 5 min) for fleet scale
- Do not put tokens/URLs with secrets into README examples
- UI breadcrumb may still show org typo “Enegy”; profile name is Energy Gateway

**Spike verified (Aug 10, 2026)**:
- Write: `POST /api/v2/write` → **204** (line protocol → `energy_metrics`)
- Read: InfluxQL via `GET /query` → **200** after creating **DBRP** mapping `energy_metrics`/`autogen` → bucket `43bdc9cfa0531940` (DBRP id `11272fcff1de9000`)
- Helper script: `api/v2/tests/spike_cloud_serverless.php`
- Note: Cloud Serverless HTTP reads for PHP are easiest via **InfluxQL `/query`** (needs DBRP). Native **SQL** is Flight/gRPC (client libs), not simple curl for AmpX portal yet.

**Not done yet**: Sunset `/api/v2/` and `influxdb2.ampx.app`; publish OTA 1.1.1; deploy theme 1.0.9

### Portal Meter Data UX (August 2026)
**Objective**: Wide readings table usable in-viewport; clarify 1000/30-day limits; export must not be limited to the table rows.

**Theme (`ampx-portal-theme` 1.0.9)**:
- Root cause of “no scrollbar”: `.table-wrapper { overflow: hidden }` clipped columns; after `overflow-x: auto`, horizontal bar sat at bottom of ~10kpx-tall table
- Fix: `max-height` on meter-data `.table-wrapper` + `overflow-x: scroll` + visible scrollbar styling so H/V bars stay in view
- Table uses `width: max-content` + `nowrap` so columns stay readable while scrolling

**Plugin (`ampx-portal-plugin` 1.1.4)**:
- Display: Influx `range(-30d)` + `limit(1000)`; constants `READINGS_RANGE_DAYS` / `READINGS_DISPLAY_LIMIT`
- Count query for UI totals (`count_meter_readings_by_serial`, field `voltage_L1`)
- Export: `admin_post_ampx_export_meter_csv` — nonce + logged-in + `user_can_access_gateway`; fetch with `$limit = null` (full 30-day set)
- UI copy states 30-day window, 1000-row table cap, and that Export is full 30-day
- Spec/plan: `ampx.app/docs/superpowers/specs/2026-08-10-meter-data-display-limit-export-design.md`

**Verified local** (gateway **100008**, SN **3423875005**): scrollbars visible; CSV 200 with matching row counts; CLI `bin/test-meter-export-limits.php`

**Ops**: Deploy theme CSS + plugin to Hetzner for live; hard-refresh after version bump.

### Shared API Key Auth (August 2026)
**Objective**: Smallest fleet-prep change — stop open writes to `/api/v2/` before scale-up.

**Implementation**:
- Server: `AMPX_API_KEY` in `api/config/config.php`; gate in `api/v2/index.php` after Content-Type check (`hash_equals`; empty config → 500; bad/missing → 401)
- Firmware: hardcoded `ampxportal_api_key` next to API URLs; `HTTPClient` sends `X-AmpX-Api-Key` in `postToAmpXPortal2()`; introduced in **1.0.3**, current stable **1.0.7**
- Docs/tests: `api/README.md`, `test_api_v2.php`, gateway README

**Verified local**:
- curl / Postman: no key or wrong key → **401**; correct key → **201** (`ampx-app.local` / `127.0.0.1`)
- Postman: header must be checked/enabled or request is unauthenticated

**Ops / live cutover**:
- Same secret in local and live `config.php`; do not put real key in public docs (use `YOUR_KEY`)
- Flash/OTA gateways with matching key **before** enabling the check on live, or production uploads get 401 (use firmware **1.0.7+**, not 1.0.3)
- Out of scope for now: per-gateway keys, NVS/Admin key UI, rate limits, upload jitter

**Breaking change note (user confirmed Aug 2026):**
- Requiring `X-AmpX-Api-Key` breaks all pre-1.0.3 gateways (401). Accepted because **no live field gateways** existed yet.
- **Policy going forward:** every breaking API/firmware contract change must bump `FIRMWARE_VERSION` (and OTA `version.json`) in the same work; document and coordinate live deploy with flash/OTA.

### HTTP Pull OTA (August 2026)
**Objective**: Enable Admin firmware updates without USB after the first OTA-capable flash.

**Implementation**:
- `HTTPUpdate` + static `WiFiClientSecure` (`setInsecure`) for HTTPS; static `WiFiClient` for HTTP (local test)
- Admin: Check for update + Update Firmware; last OTA status/time in NVS (`ota_status` / `ota_time`)
- `POST /update` sends status page then downloads/flashes; success → NVS + reboot
- Board: **ESP32 Dev Module**, Flash **8MB**, partition **custom** (`partitions.csv` dual OTA app slots)
- Host path: `D:\xampp\htdocs\ampx.app\firmware\` + junction `htdocs\firmware` for LAN IP access
- Deploy helper: `ampx.app/firmware/deploy-firmware.ps1` (needs `AMPX_FTP_PASS`)

**Verified**:
- Negative: live URL 404 → Admin `Failed: File Not Found (404)`
- Positive: local `http://{LAN_IP}/firmware/...` OTA 1.0.1 → **1.0.2**, Home/Settings OK after reboot
- USB baseline flash on COM5 with custom 8MB partitions

**Ops**: Live `public_html/firmware/` hosts **1.0.7** `.bin` + `version.json` (verified Aug 18). Keep both files in sync when publishing.
### Live Portal Meters Fix + Live API E2E (July 2026)
**Objective**: Prove gateway uploads work against live AmpX API and appear on https://ampx.app; fix Meters critical error for gateway 100007.

**Root cause (meters critical error)**:
- Live `wp-config.php` was missing `AMPX_INFLUXDB_URL` / `TOKEN` / `ORG` / `BUCKET`
- Plugin `AMPX_Portal_Config` throws if those constants are undefined when Meters loads Influx
- After adding constants, PHP **OPcache** still served the old `wp-config` until `opcache_reset()`

**Also hardened (local + deployed to live plugin)**:
- `class-ampx-portal-influxdb-detailed.php`: robust Influx annotated-CSV parse; `str_getcsv(..., ',', '"', '\\')` for PHP 8.4
- `class-ampx-portal-public.php`: try/catch around meters shortcode; admin-visible error; build marker `ampx-meters-build:2026-07-25b`

**Live ops**:
- Host: Hetzner `dedivirt3789.your-server.de`, FTP user `ampxapp`, docroot `public_html` → `/usr/www/users/ampxapp/`
- PHP **8.4**; WP debug log via Debug Log Manager path in `WP_DEBUG_LOG` (not `wp-content/debug.log`)
- Apache `www_logs/ampx.app/` is mostly scanner noise — use the Debug Log Manager file for PHP fatals
- Gateway must exist in WP Admin and be assigned to the user (Influx data alone does not register a gateway)

**Verified live**: Gateway **100007**, meter SN **2724193004**, Meters list + View Data (~74 readings); ESP posts **201** to live API.

### Local API + Portal Verification (July 2026)
**Objective**: Prove gateway uploads work against local AmpX API and appear in the local portal.

**Working path**:
1. Gateway `USE_LOCAL_SERVER true` → `http://{PC_LAN_IP}/api/v2/` (port **80**, not 8080)
2. XAMPP serves `D:\xampp\htdocs\ampx.app\api\v2\` (junction `D:\xampp\htdocs\api` → `ampx.app\api` so IP-based requests work)
3. API writes to InfluxDB (`https://influxdb2.ampx.app`, bucket `energy_metrics`, tags `gateway` / `meter` / `serial_number`)
4. Portal at **http://ampx-app.local/** (vhost `ampx-app.local` → `htdocs/ampx.app`). Public **ampx.app** is Cloudflare live site — do not confuse with local.

**Verified**: Gateway **100007**, meter **1**, serial **2724193004** → HTTP **201** on Serial; portal Meters + View Data show readings.

**Ops pitfalls**:
- Old URL `http://192.168.2.32:8080/api/v2/` is obsolete
- ESP `connection refused` to PC:80 often = Windows Firewall / network profile; Wi‑Fi **Private** + Apache inbound allow
- Firmware “No internet connection” on connection-refused is misleading
- NTP: ~15s max wait (exits early on success)
- Meter discovery: `break` on first failed Modbus ID (contiguous IDs 1..N)

**API docs**: `D:\xampp\htdocs\ampx.app\api\README.md` (gateway README links only).

### WebSocket Loop Servicing Fix (July 2026)
**Objective**: Fix multi-minute WebSocket “Connecting…” after HTTP page already loaded.

**Minimal Fix** (meter-read block): call `server.handleClient()` + `webSocket.loop()` before and after `handlePowerMeter()`.

**Related**: SoftAP DHCP on Windows; 8MB flash / OTA partition; OneDrive compile slowdowns.

### Staggered Meter Reading (January 2025)
One meter per 1s interval; sub-3s WebSocket connections; progressive UI updates.

### UI / WebSocket / 5-Meter Work (Oct–Dec 2024)
Sidebar UI, meters page, WebSocket architecture, 5-meter expansion — see progress.md / .cursorrules Sessions 1–5.

## Next Development Opportunities
1. **Next:** Implement and publish chip-aware OTA **1.2.0** (`targets` only). Plan: `memory-bank/plans/2026-08-23-multi-chip-ota.md`. Do not publish **1.0.9** or single-url **1.1.1**.
2. USB-flash 100007 with 1.2.0 **before** live catalog; then migrate remaining `/api/v2/` units
3. Deploy theme **1.0.9**; then sunset v2 / Influx 2
4. Optional: 100007 voltage zeros (Modbus); TCP Modbus register probe; RS485 `modbus_test_connection()`; scale HTML meters; Windows mDNS

## System Health Status
- **Firmware**: USB **1.1.1** on **100007** (live `/api/v3/`); local sketch **1.2.1** + `CHIP_OTA_KEY` (OTA parse unfinished; TCP sweep socket Sep 28). Do not flash 1.0.3 or 1.0.4/1.0.5
- **Local + live API v3**: Key enforced; Cloud writes 201 verified
- **API v2**: Still on Hetzner → Influx 2; live portal does not read it
- **Influx (portal)**: Cloud Serverless org **Energy Gateway**
- **Portal**: Plugin **1.1.5** InfluxQL; live + local Meter Data for 100007 / 3423875005
- **Theme**: 1.0.9 local, **1.0.7** live
- **OTA hosting**: Live `version.json` **1.0.9**; next publish chip-aware **1.2.0** (not 1.1.1)

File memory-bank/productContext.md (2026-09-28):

# Product Context - AmpX Open Energy Gateway

## Problem Statement
Industrial and commercial facilities need comprehensive energy monitoring across multiple zones, departments, or tenants. Traditional solutions are often expensive, proprietary, or require complex infrastructure. There's a need for an open, cost-effective gateway that can aggregate data from multiple energy meters and provide both local monitoring and centralized data collection.

## Target Users

### Primary Users
- **Energy Managers**: Need real-time visibility into energy consumption patterns
- **Facility Managers**: Require multi-zone monitoring for cost allocation
- **System Integrators**: Deploy energy monitoring solutions for clients
- **Manufacturing Operations**: Monitor energy usage across production lines

### Use Cases
- **Manufacturing Facilities**: Multi-zone energy monitoring across production areas
- **Commercial Buildings**: Tenant energy tracking and billing
- **Energy Auditing**: Standardized data collection for efficiency assessments
- **Remote Monitoring**: Centralized meter management across multiple sites

## Solution Design

### Core Value Propositions
1. **Cost-Effective**: Open-source solution using affordable ESP32 hardware
2. **Scalable**: Monitor up to 32 meters from single gateway
3. **Flexible**: Support for both RS485 and TCP/IP communication
4. **Real-Time**: Live web interface with WebSocket updates. TCP uses one Modbus socket per sweep and services the WebSocket between registers (Meter Details ~5 s on 28 Sep 2026, down from ~40 s)
5. **Cloud-Ready**: Automatic data upload to AmpX Portal API (local XAMPP or live `ampx.app`) with shared `X-AmpX-Api-Key`; firmware **1.2.1** posts `/api/v3/` (frequency and per-phase power factor included; not `power_factor_tot`); portal Meters/View Data read Cloud Serverless via InfluxQL (Influx 2 remains on `/api/v2/` until sunset)

### User Experience Goals
- **Plug-and-Play Setup**: WiFiManager for easy network configuration; Admin Clear WiFi (ship-mode) so a boxed unit boots AP at the customer site
- **Auto-Discovery**: Automatic meter detection and configuration
- **Intuitive Interface**: Clean web dashboard showing all meter data
- **Portal Meter Data**: Scrollable wide tables; clear 1000-row / 30-day display limits; CSV export of full 30-day window
- **Field firmware updates**: Admin Check for update + HTTP OTA from `ampx.app/firmware/` (no USB after first flash)
- **Mobile-Friendly**: Responsive design for smartphone/tablet access
- **Status Visibility**: LED indicators for system health monitoring; LEDs off immediately before Admin reboot / Clear WiFi restart

## Data Flow Architecture
```
Energy Meters → Modbus (RS485/TCP) → ESP32 Gateway → Local Web Interface
                                                   ↓
                                              WiFi Network
                                                   ↓
                                              AmpX Portal API
```

## Competitive Advantages
- **Open Source**: No vendor lock-in, customizable
- **Multi-Protocol**: Supports both RS485 and TCP/IP variants
- **Low Cost**: ESP32-based hardware vs expensive commercial gateways
- **Real-Time**: Live updates vs batch reporting
- **Modular**: Extensible architecture for future enhancements

## Success Criteria
- Stable operation in industrial environments
- Accurate data collection and transmission
- User-friendly setup and configuration
- Reliable 24/7 operation
- Integration compatibility with existing energy management systems

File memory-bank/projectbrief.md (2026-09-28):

# AmpX Open Energy Gateway - Project Brief

## Project Overview
**Name**: AmpX Open Energy Gateway  
**Platform**: ESP32 (Node32S)  
**License**: MIT  
**Purpose**: Industrial energy monitoring gateway for Meatrol brand energy meters

## Core Mission
Create a comprehensive ESP32-based energy monitoring gateway that communicates with up to 32 Meatrol energy meters via Modbus protocols (RS485 and TCP/IP), provides real-time web interface monitoring, and uploads data to remote API for centralized energy management.

## Key Requirements

### Hardware Support
- ESP32 Wroom 32U microcontroller
- Dual communication variants:
  - **RS485 Version**: MAX485 interface for serial communication
  - **TCP/IP Version**: W5500 Lite Ethernet module for network communication
- 4 status LEDs for system monitoring
- WiFi connectivity with WiFiManager

### Core Functionality
- **Multi-meter support**: Monitor up to 32 energy meters simultaneously
- **Real-time monitoring**: 3-second update intervals for web interface
- **Data collection**: Voltage, current, power, and energy readings per phase
- **Web interface**: Live dashboard with WebSocket updates
- **API integration**: Automatic ~30-second uploads to AmpX Portal (local or live) authenticated with shared API key header; **`/api/v3/`** writes InfluxDB Cloud Serverless (live + local). `/api/v2/` still writes InfluxDB 2 (`influxdb2.ampx.app`) until sunset.
- **Field updates**: HTTP OTA from Admin after first USB flash (8MB dual-app partitions). Sketch and live catalog **1.2.1** (single `version` + `url`, 28 Sep 2026). Gateway **100007** is the TCP/IP unit. Cloudflare bypasses cache for `/firmware/`. Chip-aware `targets` is not parsed yet. Do not publish **1.0.9** or an S3 image at the legacy `.bin` URL.
- **Auto-discovery**: Automatic detection of connected meters

### Data Management
- Modbus register reading and processing
- JSON data serialization
- Non-volatile storage (NVS) for settings
- Real-time timestamp synchronization via NTP
- AmpX Portal Meter Data: display newest 1000 readings / last 30 days; CSV export of full 30-day window

## Technical Constraints
- Arduino IDE development environment
- Memory optimization for ESP32 platform
- Modular code structure with separate .ino files
- Web interface via header files (SPIFFS option available for future)
- Debug output control for production builds

## Success Metrics
- Reliable communication with multiple meters
- Real-time web interface performance
- Successful API data transmission
- System stability over 24-hour operation cycles
- Industrial-grade reliability for commercial deployments

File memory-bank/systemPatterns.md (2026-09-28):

# System Patterns - AmpX Open Energy Gateway

## Architecture Overview

### Modular Design Pattern
The system uses a clean separation of concerns with multiple `.ino` files:

```
open_energy_gateway.ino     # Main application & coordination
├── functions.ino           # Core utilities & NVS
├── functions_modbus.ino    # Modbus communication & data processing
├── functions_web.ino       # Web server & WebSocket handling
├── functions_wifi.ino      # WiFi management with WiFiManager
├── functions_ethernet.ino  # Ethernet initialization (TCP/IP variant)
├── functions_meter.ino     # Meter service (serviceMeters), discovery, registers
├── functions_api.ino       # Remote API communication
├── functions_ntp.ino       # Time synchronization
└── functions_ota.ino       # HTTP pull OTA (Admin Check + Update)
```

### Hardware Abstraction Pattern
Conditional compilation for different hardware variants:
```cpp
#define MODBUS_TYPE_RS485 1
#define MODBUS_TYPE_TCPIP 2
#define MODBUS_TYPE MODBUS_TYPE_TCPIP  // Set variant here

#if MODBUS_TYPE == MODBUS_TYPE_RS485
    // RS485-specific code
#else
    // TCP/IP-specific code
#endif
```

## Data Processing Patterns

### Register Processing Pipeline
1. **Read Modbus Registers**: Raw 16-bit values from meters
2. **Type Conversion**: Convert based on data type (int32, int64, float)
3. **JSON Serialization**: Store in global JsonDoc for web interface
4. **WebSocket Broadcasting**: Real-time updates to connected clients

### Data Type Handling
```cpp
const int dataTypeInt32 = 1;  // 2 registers → 32-bit integer
const int dataTypeInt64 = 2;  // 4 registers → 64-bit integer (energy)
const int dataTypeFloat = 3;  // 2 registers → 32-bit float
```

### JSON Document Pattern
Global `DynamicJsonDocument` serves as central data store:
- Updated by Modbus reading functions
- Consumed by WebSocket for real-time updates
- Serialized for API transmission

## Communication Patterns

### WebSocket Real-Time Updates
- Staggered meter reading (one meter per ~1s interval) with immediate JSON broadcast
- No polling required from web interface
- Comprehensive error handling with automatic reconnection
- Connection status indicators for user feedback
- All dynamic content updates via WebSocket (no server-side string replacement)

### Non-Blocking Network Servicing (Critical)
Blocking Modbus (`modbus_test_connection`, each register read) prevents WebSocket handshakes if the network stack is not serviced. **Required pattern:**

- Around the sweep in `readNextMeter()`: `server.handleClient()` / `webSocket.loop()`, then `handlePowerMeter()`, then `handleWebSocket()` (one JSON broadcast), then service again.
- **Inside** the register loop in `handlePowerMeter()`, before each Modbus read: `server.handleClient()` + `webSocket.loop()` only. Do not broadcast there.

Also keep `server.handleClient()` / `webSocket.loop()` at the end of `loop()`. UI “Connecting…” = waiting on port 81; HTTP page load does not imply WebSocket is up.

**Boot note**: `setup()` does not service clients until it returns — NTP sync (up to ~15 s) can delay the first page. That is separate from the meter sweep.

### One Modbus TCP socket per sweep (September 2026)
About 20 Meatrol values used to each `connect()` + `stop()` on port 502, plus a fixed `delay(100)` and a test connection that also closed the socket. The WebSocket handshake waited on that, so Meter Details stayed on Connecting for up to ~40 s.

Current TCP library (`ampx_modbus_tcpip.cpp`):
- `modbus_test_connection()` opens port 502 and **leaves it open** (already connected → return true). Still not a Modbus PDU.
- `modbus_send_request()` writes on that socket; connects only if it dropped.
- `modbus_read_response()` keeps the socket on a full reply. `stop()` only when `bytesRead < 9` (7-byte MBAP + function code + byte count) or the header arrived without the register bytes.
- No `delay(100)` before the read. The response function already polls for up to 2 s and returns when the frame arrives.

Sketch closes once, at the end of `handlePowerMeter()` (`#if MODBUS_TYPE_TCPIP`). RS485 `modbus_test_connection()` is still `return true`.

Bench (28 Sep 2026), before removing `delay(100)`: about **5 seconds** to Connected plus values. Do not go back to connect/stop per register.

### Meter interval / TCP link check (August 2026)
`loop()` only times the work (`METER_CONNECTION_INTERVAL`); `serviceMeters()` in `functions_meter.ino` uses early returns:

1. `meterTransportReady()` — `#if MODBUS_TYPE_TCPIP`: `Ethernet.linkStatus() == LinkOFF` → LED 2 off, **return** (no Modbus, no `initEthernet()`). RS485: always true.
2. `modbus_test_connection()` fail → LED 2 off, return. Do **not** call `reconnectMeter()` / `initEthernet()` here (`delay(2000)` freezes HTTP/WebSocket).
3. Success → LED 2 on, `readNextMeter()`.

Do **not** call `Ethernet.linkStatus()` from `ampx_modbus_tcpip.cpp` (Cursor/clangd: undeclared `Ethernet` / `LinkOFF`). Do **not** name the loop helper `handleMeters()` — that is the `/meters` web handler.

### Breaking-change versioning
- If a change makes previously flashed gateways fail against the portal/API, bump `FIRMWARE_VERSION` in the same change (and publish matching `version.json` for OTA).
- API key auth (Aug 2026) was such a break: pre-1.0.3 devices get **401**. Allowed then only because no field fleet existed.

### Time-series hosting pattern (August 2026)
- **Production (portal + firmware 1.1.1)**: Managed **InfluxDB Cloud Serverless** (account **AmpX** / org **Energy Gateway** / AWS Frankfurt) via `/api/v3/`
- **Legacy**: InfluxDB 2 at `influxdb2.ampx.app` via `/api/v2/` — still deployed; live portal no longer reads it
- **Avoid**: Self-hosting InfluxDB on the Hetzner WordPress host; renaming the Cloud org to AmpX (account ≠ org; quota is one org)
- **AmpX API v3**: Isolated `/api/v3/` writes Cloud Serverless (`INFLUXDB_CLOUD_*`, **org ID** on write URL); same JSON + `X-AmpX-Api-Key` as v2; `api_version` **3.0**

### API Upload Pattern
- 30-second interval for remote server uploads (`postToAmpXPortal2`)
- JSON: `gateway_id`, `meter_id`, `serial_number`, `timestamp`, `values{mN_*}`
- Auth: HTTP header `X-AmpX-Api-Key` = sketch `ampxportal_api_key` = `AMPX_API_KEY` in `api/config/config.php` (shared fleet secret; `hash_equals` on server)
- Missing/wrong key → **401** before validation/Influx; empty server config → **500**
- Success = HTTP **201**; Influx tags: `gateway`, `meter`, `serial_number`; measurement `meter_readings_detailed`
- Configurable local vs live via `USE_LOCAL_SERVER` / `ampxportal_server_local` | `_live`
- Local = XAMPP API on LAN IP port 80 `/api/v3/`; live = `https://ampx.app/api/v3/` (key gate verified 401/201 Aug 22). v2 URLs still work for Influx 2 writes.
- Portal reads Cloud via plugin InfluxQL (`class-ampx-portal-influxdb-detailed.php`); UI at `/meters/?gateway_id=` and `/meter-data/?meter_sn=&gateway_id=`

### HTTP OTA Pattern (live catalog **1.2.1** since 28 Sep 2026)

**Live catalog** is still top-level `version` + `url` (not `targets`). Chip-keyed `targets.esp32` / `targets.esp32s3` remains a plan: `ampx.app/docs/superpowers/specs/2026-08-23-multi-chip-ota-design.md`. This firmware reads `doc["version"]` and `doc["url"]` only.

**Cloudflare:** `ampx.app` is proxied. Cache rule **Bypass firmware OTA** (URI Path starts with `/firmware/`) must stay on. Without it the gateway can flash a cached older `.bin` while `version.json` is already newer. `OK: update applied (X)` stores the manifest version, then reboots; **Current firmware version** is the string inside the image that booted.

**Publish:** ESP32 Dev Module (not S3) → Export Compiled Binary → `open_energy_gateway.ino.bin` renamed to `public_html/firmware/ampx_open_energy_gateway.bin`, plus `version.json` with the same `FIRMWARE_VERSION`. Export the application `.bin`, not the merged or bootloader file.
- Admin HTML must **not** call outbound `HTTPClient` in web handlers — that caused `ERR_CONNECTION_RESET` / hangs
- Flow: **Check for update** → `GET /ota_status?refresh=1` sets `otaManifestCheckRequested` → `loop()` runs `serviceOtaManifestCheck()` → fills `otaStatusCache` → JS polls `/ota_status` (no `refresh`). Opening `/admin` does **not** start TLS
- **Never** fetch the manifest from a FreeRTOS side task: 1.0.3 used `otaManifestTask` on core 0 with boot-time HTTPS → LoadProhibited reboot loop (**1.0.4** moved check to `loop()`)
- **Never** declare `WiFiClientSecure` as a local in `loop()` / `fetchFirmwareManifest()`: 1.0.4/1.0.5 stack overflow → `TG1WDT_SYS_RESET` on Check. Use **static** `otaTlsClient` / `otaPlainClient` + `SET_LOOP_TASK_STACK_SIZE(16384)`
- Do not share Arduino `String` objects across cores without a mutex (prefer loop-only access)
- Compare versions with `isNewerVersion()` (`major.minor.patch` numeric). Update only if server **>** device. Equal or older server → “Up to date”, button **disabled**
- Manifest fetch fail → “Unavailable”; button may stay enabled for a manual attempt
- `POST /update` re-checks; refuses if server is not newer; download URL from manifest `url` (local mode forces `firmwareURL`); flash via `HTTPUpdate`
- Host both `ampx_open_energy_gateway.bin` and `version.json` under `/firmware/` (keep in sync on publish)
- ArduinoOTA not used; first flash via USB with dual OTA partitions, then field updates via Admin

### Ship-mode / Clear WiFi (August 2026)
- Admin **Clear WiFi (Ship Mode)** → `POST /clear_wifi` with `ADMIN_PASSWORD` (same as Gateway ID)
- `clearStoredWifi()` → `WiFiManager.resetSettings()` then LEDs off then `ESP.restart()`
- Do **not** call `resetSettings()` from `initWiFi()` — that wipes credentials on every boot
- Clears WiFi only; Gateway ID / meter names / OTA NVS stay
- After reboot, `autoConnect` starts open AP `energy-gateway-{GATEWAY_ID}`; portal `http://192.168.4.1`
- Standalone status HTML: use ASCII `-` not a UTF-8 em dash unless `<meta charset="UTF-8">` is present (`—` became `â€"`)
- Admin Reboot (`handleRebootGateway`) also turns all five LEDs `LOW` before `ESP.restart()`
- WiFiManager `/wifisave` message: `setCustomHeadElement()` JS replaces `.msg` when it contains “Trying to connect”; tell the customer to open `http://energy-gateway-{ID}.local` or the IP from their router. `setCustomHeadElement` stores a **pointer** — the `String` must stay in scope until `autoConnect()` returns

### Portal Influx Config Pattern (WordPress)
- Plugin never hardcodes Influx credentials; `AMPX_Portal_Config` requires `AMPX_INFLUXDB_*` constants in `wp-config.php`
- Meters page fails hard (or admin error box) if those constants are missing
- On PHP 8.4 hosts: always pass `$escape` to `str_getcsv`; skip Influx `#` annotation CSV lines
- After deploying `wp-config.php` on OPcache hosts (Hetzner): flush OPcache before testing
- WP gateway table is separate from Influx: assign gateway to user in admin before portal UI shows it

### Portal Meter Data Pattern (August 2026; Cloud reads Aug 22)
- **Queries (local + live)**: InfluxQL `GET /query?db=energy_metrics` (not Flux); `time >= now() - 30d` (`READINGS_RANGE_DAYS = 30`). `AMPX_INFLUXDB_ORG` must be **Energy Gateway** (required by config; not currently on the query URL).
- **Table**: newest `READINGS_DISPLAY_LIMIT` (1000) via InfluxQL `LIMIT`; UI must state both caps
- **Meter Data page**: keep only `[ampx_meter_data]` in WP; do not leave Kadence example HTML (100001 / Test was leftover until 22 Aug 2026)
- **Export CSV**: must not scrape the DOM — use `admin_post_ampx_export_meter_csv` with nonce + gateway ACL; Influx fetch with `$limit = null` (same 30d window, no row cap)
- **Wide tables**: theme `.meter-data-container .table-wrapper` needs `max-height` + `overflow-x: scroll` so the horizontal scrollbar stays in the viewport (bar at end of full table height is invisible)
- Avoid `.table-wrapper { overflow: hidden }` for meter readings — it clips columns with no scroll

### Status LED Feedback Pattern
```cpp
LED_1_POWER     // Power on indicator
LED_2_METER     // Modbus communication status
LED_3_WIFI      // WiFi connection status
LED_4_INTERNET  // Internet connectivity
LED_5_SERVER    // Successful API communication
```

## Memory Management Patterns

### Debug Output Control
```cpp
#define DEBUG 1
#if DEBUG == 1
  #define debug(x) Serial.print(x)
  #define debugln(x) Serial.println(x)
#else
  #define debug(x)
  #define debugln(x)
#endif
```

### Preferences Storage Pattern
- Non-volatile storage for meter names and settings
- Key-value pairs: `m1_name`, `m2_name`, etc.
- Persistent across reboots

### Web Interface Storage
- **Current Implementation**: HTML templates in header files
- **WebSocket Architecture**: All dynamic content updates via WebSocket JSON transmission
- **Template System**: Static HTML with JavaScript-based DOM updates
- **Memory Efficiency**: Static allocation in program memory
- **Future SPIFFS Option**: Infrastructure ready for deployment

## Error Handling Patterns

### Connection Management
- Automatic reconnection on Modbus failures
- WiFi reconnection with WiFiManager fallback
- Graceful degradation when meters are offline

### Power Supply Management
- **Development**: Direct USB connection to avoid power supply issues
- **WiFi Power Spikes**: Monitor for voltage drops during high-current operations
- **Production**: External power supply recommended for industrial deployments
- **Diagnostic**: Garbled serial output indicates power supply instability

### Timeout Handling
- NTP synchronization timeout (20 seconds)
- Meter communication timeouts
- Configurable retry mechanisms

## Timing Patterns

### Multi-Timer System
```cpp
static unsigned long counter1 = 0;  // Meter reading (3s)
static unsigned long counter2 = 0;  // API upload (30s)
static unsigned long counter3 = 0;  // Reboot timer (24h)
```

### Non-Blocking Operations
- `millis()` based timing instead of `delay()`
- Continuous `server.handleClient()` and `webSocket.loop()`
- Preserves real-time responsiveness

## Security Patterns

### Network Security
- WiFiManager with AP mode for initial setup
- HTTPS API endpoints for data transmission
- No hardcoded credentials in code

### Gateway Identification
- Unique `AMPX_GATEWAY_ID` for device identification
- Serial number tracking for individual meters
- Structured data format for audit trails

## Scaling Patterns

### Current Limitations (4-Meter Hardcoded)
- **HTML Templates**: Static meter sections in `webpage.h` and `web_settings.h`
- **Global Variables**: `m1_serial_number` through `m4_serial_number` pattern
- **Server Code**: Hardcoded meter handling loops
- **JavaScript**: Static meter references in WebSocket processing

### Scaling Strategy for 10+ Meters
- **Dynamic HTML Generation**: Template-based meter section creation
- **Array-Based Data**: Replace global variables with meter arrays
- **Loop-Based Processing**: Dynamic meter handling in server and client code
- **WebSocket Scalability**: JSON-based updates support unlimited meters
- **Memory Management**: Efficient data structures for large meter counts

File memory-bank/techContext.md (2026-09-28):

# Technical Context - AmpX Open Energy Gateway

## Development Environment

### Platform & IDE
- **Primary IDE**: Arduino IDE (recommended)
- **Alternative**: PlatformIO
- **Target Board**: ESP32 Node32S (ESP32 Wroom 32U)
- **Board Package**: ESP32 by Espressif Systems
- **Board Manager URL**: `https://raw.githubusercontent.com/espressif/arduino-esp32/gh-pages/package_esp32_index.json`

### Power Supply Requirements
- **Development**: Direct PC USB connection required (avoid USB hubs)
- **WiFi Operations**: Peak current draw 200-300mA during connection attempts
- **Production**: Consider external power supply for industrial deployments
- **Stability**: USB hubs can cause voltage drops and power supply noise

### Build Configuration
- **Partition Scheme**: "Minimal SPIFFS (1.9MB APP with OTA/190KB SPIFFS)" or "Huge APP (3MB No OTA/1MB SPIFFS)"
- **Serial Baud Rate**: 115200 (sketch `Serial.begin(115200)`)
- **Debug Level**: Configurable via `#define DEBUG 1`

## Hardware Specifications

### ESP32 Configuration
- **Microcontroller**: ESP32 Wroom 32U
- **Flash Memory**: Program + SPIFFS storage
- **RAM**: Dynamic JSON documents up to 2048 bytes
- **GPIO**: Multiple pins for status LEDs and communication interfaces

### Communication Variants

#### RS485 Variant
```cpp
#define MAX485_DE 4     // Driver Enable (White)
#define MAX485_RE_NEG 4 // Receiver Enable (Active Low)
#define RX_PIN 16       // Receive Pin (Orange)
#define TX_PIN 17       // Transmit Pin (Yellow)
// Modbus A (Positive, Green), Modbus B (Negative, Blue)
```

#### TCP/IP Variant
```cpp
#define ETH_SPI_SCS_PIN 5  // Chip Select for W5500
// Hardware SPI: SCK=18, MISO=19, MOSI=23
byte mac[] = {0x90, 0xA2, 0xDA, 0x0E, 0x94, 0xB5};
IPAddress ip(192, 168, 1, 50);
IPAddress gateway(192, 168, 1, 1);
IPAddress subnet(255, 255, 255, 0);
IPAddress meter_ip(192, 168, 1, 55);
```

### Status LEDs
```cpp
#define LED_1_POWER     12  // Power indicator
#define LED_2_METER     14  // Meter communication
#define LED_3_WIFI      27  // WiFi connection
#define LED_4_INTERNET  26  // Internet connectivity
#define LED_5_SERVER    25  // Server communication
```

## Dependencies

### Required Arduino Libraries
```cpp
#include <WiFi.h>              // ESP32 built-in WiFi
#include <WebServer.h>         // HTTP server functionality
#include <WebSocketsServer.h>  // Real-time updates (Markus Sattler)
#include <ArduinoJson.h>       // JSON processing (Benoit Blanchon)
#include <HTTPClient.h>        // HTTP client for API calls
#include <WiFiManager.h>       // WiFi configuration (tzapu)
#include <Preferences.h>       // Non-volatile storage (Vlodomyr Shymanskyy)
#include <HardwareSerial.h>    // RS485 communication
#include <time.h>              // NTP time synchronization
```

### Custom Libraries
- **Repository**: [AmpXModbus](https://github.com/Johannf78/AmpXModbus)
- **RS485 Variant**: `ampx_modbus_rs485.h` (custom AmpX library)
- **TCP/IP Variant**: `ampx_modbus_tcpip.h` (custom AmpX library at `Documents/Arduino/libraries/ampx_modbus_tcpip`)
- **TCP socket (Sep 2026)**: one connection per sweep. `modbus_test_connection()` is `connect(meter_ip, 502)` and **leaves it open** (not a Modbus PDU). `modbus_send_request()` reuses it. `modbus_read_response()` `stop()`s only on a short frame (`< 9` bytes) or a header without register bytes. Sketch `handlePowerMeter()` closes once at the end. No per-register `delay(100)`.
- **Ethernet link check**: `Ethernet.linkStatus() == LinkOFF` in sketch `meterTransportReady()` (`functions_meter.ino`), not in the TCP library (IDE cannot see `Ethernet` / `LinkOFF` there)
- **Installation**: Clone repository and copy to `Documents/Arduino/libraries/` folder

## Data Structures

### JSON Documents
```cpp
DynamicJsonDocument JsonDoc(2048);        // Main data storage
JsonDocument MeterRegisterDefs;           // Register definitions
```

### Meter Register Format
```cpp
// Format: [register_address, num_registers, data_type, friendly_name, json_key]
// Data Types: 1=int32, 2=int64, 3=float
[70, 2, 1, "Serial Number", "serial"]
[1010, 2, 3, "Voltage L1", "voltage_L1"]
[2500, 4, 2, "Energy Imported L1", "active_energy_imported_L1"]
```

## Network Configuration

### WiFi Setup
- **AP Mode**: `energy-gateway-{GATEWAY_ID}` (open / no password) — first boot and after Admin Clear WiFi
- **Hostname / mDNS**: `energy-gateway-{GATEWAY_ID}` (`.local` often fails on Windows; use IP)
- **Config portal**: `http://192.168.4.1` (WiFiManager); save-page copy customized in `initWiFi()`
- **Web Server**: Port 80
- **WebSocket**: Port 81
- **Admin password**: `ADMIN_PASSWORD` in `open_energy_gateway.ino` (Gateway ID + Clear WiFi); do not put the value in public docs

### API Endpoints
```cpp
// Local: PC LAN IP + XAMPP on port 80 (update IP when DHCP changes)
const char* ampxportal_server_local = "http://192.168.2.120/api/v3/";
const char* ampxportal_server_live = "https://ampx.app/api/v3/";
const char* ampxportal_api_key = "...";  // must match AMPX_API_KEY in api/config/config.php
#define USE_LOCAL_SERVER false  // 1.1.1 production Cloud path; true → LAN /api/v3/
```

### Local AmpX stack (July–August 2026)
- **API code**: `D:\xampp\htdocs\ampx.app\api\` — v2 `POST /api/v2/` (Influx 2); v3 `POST /api/v3/` (Cloud Serverless, local + live) — docs: `api/README.md`
- **Auth**: Required header `X-AmpX-Api-Key` (local + live v3 verified August 2026); value from `AMPX_API_KEY` / `ampxportal_api_key`
- **Portal (WordPress)**: http://ampx-app.local/ (hosts → 127.0.0.1; Apache vhost DocumentRoot `htdocs/ampx.app`)
- **LAN access to API**: junction `D:\xampp\htdocs\api` → `ampx.app\api` so `http://{LAN_IP}/api/v2/` works
- **LAN access to firmware**: junction `D:\xampp\htdocs\firmware` → `ampx.app\firmware` so `http://{LAN_IP}/firmware/*.bin` works
- **InfluxDB (legacy v2)**: `https://influxdb2.ampx.app`, org `ampx`, bucket `energy_metrics`, measurement `meter_readings_detailed`
- **Success**: HTTP **201** + portal meters page for the gateway; **401** if key missing/wrong
- **Postman**: Local URL `http://ampx-app.local/api/v2/` or `http://127.0.0.1/api/v2/`; enable `X-AmpX-Api-Key` header
- **Do not use**: `:8080` unless a Docker API container is running; public DNS `ampx.app` ≠ local vhost

### InfluxDB Cloud Serverless (production portal + v3 — August 2026)
- **Product**: Managed InfluxDB Cloud Serverless (not self-hosted on Hetzner; not early-access “InfluxDB 3 Cloud”)
- **Account**: AmpX · **Organization**: Energy Gateway · **Org ID**: `86a141bfd8d7f66a`
- **Region**: AWS `eu-central-1` (EU Frankfurt)
- **Host**: `https://eu-central-1-1.aws.cloud2.influxdata.com`
- **Bucket**: `energy_metrics` (ID `43bdc9cfa0531940`, retention 30 days)
- **Docs**: https://docs.influxdata.com/influxdb3/cloud-serverless/
- **Writes**: v1/v2-compatible `/api/v2/write` + line protocol (spike **204** OK)
- **Queries (HTTP/PHP-friendly)**: InfluxQL on `GET /query?db=energy_metrics` — requires **DBRP** mapping (created: database `energy_metrics` / rp `autogen` → bucket id `43bdc9cfa0531940`)
- **Queries (native SQL)**: Flight+gRPC client libraries (not used in spike)
- **Token**: local `INFLUXDB_CLOUD_TOKEN` in `api/config/config.php` (v2 still uses legacy `INFLUXDB_*`); rotate if exposed
- **Spike script**: `api/v2/tests/spike_cloud_serverless.php`
- **AmpX wiring**: Local + live `/api/v3/` writes + portal InfluxQL reads verified 22 Aug 2026 (100007 / 3423875005); never put Cloud token in README
- **Upgrade path if needed**: Cloud Dedicated (sales), not DIY Core on the WP host

### Live AmpX portal (July 2026)
- **Site**: https://ampx.app/ (Hetzner `dedivirt3789.your-server.de`, FTP `ampxapp`, PHP **8.4**)
- **API**: `https://ampx.app/api/v3/` (Cloud); `https://ampx.app/api/v2/` still on Influx 2. Live v3 key gate verified GET **405**, POST no key **401**, keyed POST **201**.
- **Portal plugin**: `ampx-portal-plugin` (**1.1.5**) — InfluxQL against Cloud (`AMPX_Portal_InfluxDB_Detailed`)
- **Portal theme**: `ampx-portal-theme` (**1.0.9** local, **1.0.7** live) — table scroll CSS not on live yet
- **Meter Data page**: `/meter-data/?meter_sn=&gateway_id=` — table ≤1000 newest / 30d; Export CSV = full 30d via `admin-post.php?action=ampx_export_meter_csv`
- **Required in live `wp-config.php`** (before “stop editing”):
  - `AMPX_INFLUXDB_URL`, `AMPX_INFLUXDB_TOKEN`, `AMPX_INFLUXDB_ORG`, `AMPX_INFLUXDB_BUCKET`
  - Local XAMPP `wp-config.php` already had these; live was missing them → WP critical error on Meters
- **OPcache**: After changing live `wp-config.php`, flush OPcache or PHP keeps old defines
- **Debug log**: `WP_DEBUG_LOG` → Debug Log Manager file under `wp-content/uploads/debug-log-manager/` (not `wp-content/debug.log`)
- **Gateway registry**: Create/assign gateway in WP Admin; Influx alone does not list a gateway
- **Design docs**: `ampx.app/docs/superpowers/specs/2026-08-10-meter-data-display-limit-export-design.md`

## Memory Management

### File System
- **Current**: HTML templates in header files (`webpage.h`, `web_settings.h`, `web_admin.h`)
- **Future SPIFFS Option**: Infrastructure ready with tools and data folder
- **Tools Available**: `create_spiffs.bat`, `upload_spiffs.bat`, `spiffsgen.py`
- **Web Assets Ready**: `index.html`, `settings.html`, `admin.html`, `meter_registers_meatrol.json`

### Storage Optimization
- Conditional debug output compilation
- Static string templates with runtime replacement
- Optimized JSON document sizing
- HTTP OTA enabled (ArduinoOTA not used); sketch ~1.3MB fits dual ~2.1MB OTA app slots in `partitions.csv`

## Timing & Performance

### Update Intervals
```cpp
const unsigned long METER_CONNECTION_INTERVAL = 1000;   // 1 second (staggered: one meter per tick)
const unsigned long REMOTE_SERVER_INTERVAL = 30000;     // 30 seconds  
const unsigned long REBOOT_INTERVAL = 86400000;         // 24 hours
```

### Processing Pipeline
1. **Meter Reading**: One meter per 1-second interval (full cycle ≈ numberOfMeters seconds)
2. **Network service**: `server.handleClient()` + `webSocket.loop()` before/after each meter read (required for responsive WS)
3. **WebSocket Update**: Immediate broadcast after each meter read
4. **API Upload**: 30-second intervals
5. **Status Monitoring**: Continuous LED status updates

### Flash / OTA (August 2026)
- Target: **8MB** modules — Arduino IDE **ESP32 Dev Module**, Flash **8MB**, Partition **custom** (`src/open_energy_gateway/partitions.csv` dual OTA apps) or **8M with spiffs**
- Sketch string is **`FIRMWARE_VERSION` 1.2.1**. Live `version.json` is **1.2.1** with top-level `url` (published 28 Sep 2026). `fetchFirmwareManifest()` does not read `targets` yet. Cloudflare cache rule bypasses `/firmware/`. Confirm the booted image on **100007** (a cached 1.0.9 bin was flashed once while the status line said 1.2.1). Never an S3 `.bin` at the legacy URL. Do not ship 1.0.3, 1.0.4/1.0.5, or put **1.0.9** back. Plan for chip-aware catalogs: `memory-bank/plans/2026-08-23-multi-chip-ota.md`.
- `SET_LOOP_TASK_STACK_SIZE(16384)` — default 8KB `loop()` stack overflows during HTTPS TLS
- Admin HTTP pull: `https://ampx.app/firmware/ampx_open_energy_gateway.bin` via `HTTPUpdate` + **static** `WiFiClientSecure`
- Manifest check: `serviceOtaManifestCheck()` from **`loop()` only** after **Check for update**; no FreeRTOS OTA task; no Admin-load or boot-time HTTPS fetch
- Local hosting: `D:\xampp\htdocs\ampx.app\firmware\` + junction `D:\xampp\htdocs\firmware` for LAN IP downloads
- Deploy live: `firmware/deploy-firmware.ps1` with `AMPX_FTP_PASS` (Hetzner `ampxapp`)
- First install still requires USB flash with OTA partitions; thereafter Admin Update Firmware
- ArduinoOTA intentionally disabled (flash size / unused for field updates)

## Security Considerations

### Network Security
- HTTPS API communication
- No hardcoded WiFi credentials
- WiFiManager for secure credential storage

### Data Integrity
- NTP time synchronization for accurate timestamps
- Serial number validation for meter identification
- JSON schema validation for API uploads

## Development Tools

### Future SPIFFS Tools (Not Currently Used)
- `spiffsgen.py`: Generate SPIFFS image from data folder
- `create_spiffs.bat`: Windows batch script for SPIFFS creation
- `upload_spiffs.bat`: Upload SPIFFS to ESP32

### Debugging
- Serial output at **115200** baud
- Configurable debug levels
- WiFi signal strength reporting
- Modbus communication status

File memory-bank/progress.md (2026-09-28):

# Progress Status - AmpX Open Energy Gateway

## ✅ Completed Features

### Core Infrastructure
- [x] **ESP32 Platform Setup**: Arduino IDE configuration with ESP32 board support
- [x] **Modular Architecture**: 9 separate `.ino` files for clean code organization
- [x] **Hardware Variants**: Conditional compilation for RS485 and TCP/IP communication
- [x] **Debug System**: Configurable debug output for development vs production

### Communication Systems
- [x] **WiFi Management**: WiFiManager integration for easy network setup
- [x] **Modbus Communication**: Support for both RS485 and TCP/IP protocols
- [x] **Web Server**: HTTP server with multiple endpoints (/, /settings, /admin)
- [x] **WebSocket Architecture**: Comprehensive real-time updates for all dynamic content
- [x] **Connection Status Indicators**: Real-time connection status and last update timestamps
- [x] **WebSocket Error Handling**: Robust reconnection logic with retry limits
- [x] **NTP Synchronization**: Accurate timestamp generation for data logging
- [x] **mDNS Service**: .local domain access with hostname `energy-gateway-{GATEWAY_ID}.local`

### Data Management
- [x] **Meter Register Definitions**: JSON-based register mapping for Meatrol meters
- [x] **Type Conversion System**: Proper handling of int32, int64, and float data types
- [x] **JSON Data Pipeline**: Unified data model with `DynamicJsonDocument`
- [x] **Non-Volatile Storage**: Preferences system for persistent settings
- [x] **Web Interface**: HTML templates in header files (SPIFFS infrastructure ready for future)

### User Interface
- [x] **Real-Time Dashboard**: Live meter readings with WebSocket-based 3-second updates
- [x] **Modern Sidebar Layout**: Professional left sidebar navigation with flexbox design
- [x] **Energy Summary Table**: L1, L2, L3, Total columns for active energy imported
- [x] **Power Summary Table**: L1, L2, L3, Total columns for active power
- [x] **Meters Detail Page**: Single meter view accessible via /meters?id=N query string
- [x] **Settings Interface**: WebSocket-powered meter naming and configuration
- [x] **Admin Interface**: Gateway configuration page structure
- [x] **Connection Status Display**: Real-time WebSocket connection status indicators
- [x] **Last Update Timestamps**: Automatic timestamp updates on all pages
- [x] **Status Indicators**: 5 LEDs for comprehensive system health monitoring
- [x] **Mobile Responsive**: Clean table-based layout for mobile devices

### API Integration
- [x] **AmpX Portal Integration**: Structured JSON uploads every 30 seconds
- [x] **Dual Server Support**: Local development and live production endpoints
- [x] **Shared API Key Auth**: `X-AmpX-Api-Key` on `/api/v2/` and `/api/v3/` (local + live v3 verified August 2026)
- [x] **Data Formatting**: Proper timestamp and meter identification in API calls
- [x] **Error Handling**: HTTP client error management and retry logic

### Operational Features
- [x] **Auto-Discovery**: Automatic meter detection during startup
- [x] **Multi-Meter Support**: Currently configured for 5 active meters, tested and operational
- [x] **Status Monitoring**: Continuous health checking with LED feedback
- [x] **Automatic Reboot**: 24-hour reboot cycle for system stability
- [x] **Gateway Reboot Function**: Web-based reboot button with countdown, auto-redirect, and LEDs off before restart
- [x] **Ship-mode / Clear WiFi**: Admin password + confirm; `resetSettings()`; reboot into AP; WiFi only (Gateway ID kept)
- [x] **WebSocket Event Handling**: Complete event handler with connection/disconnection tracking
- [x] **Staggered Meter Reading**: Sequential 1-second reads for <3-second WebSocket connections
- [x] **Optimized Performance**: Sub-3-second initial connection, progressive data updates
- [x] **TCP/IP meter service (`serviceMeters`)**: Ethernet `LinkOFF` in the sketch; skip read and `initEthernet()` when the cable is down (verified Aug 23 2026)

## 🔄 Current Capabilities

### Working Systems
- **Hardware Support**: Both RS485 (MAX485) and TCP/IP (W5500) variants operational
- **Meter Communication**: Successfully reads serial numbers, voltage, current, power, and energy
- **Web Interface**: Fully functional dashboard with real-time updates
- **Network Integration**: WiFi connectivity with automatic configuration
- **Data Logging**: Continuous uploads to AmpX Portal with proper formatting

### Tested Functionality
- **Modbus Register Reading**: All register types (int32, int64, float) properly converted
- **WebSocket Performance**: Staggered meter reads plus `handleClient`/`webSocket.loop` around each read (July 2026)
- **Progressive Data Updates**: Meters populate sequentially every 1 second
- **WebSocket Event Handler**: Fully implemented with connection tracking and error handling
- **API Communication**: Successful data transmission to remote servers
- **Fault Recovery**: Automatic reconnection on communication failures
- **Memory Management**: Stable operation within ESP32 memory constraints
- **5-Meter Operation**: Successfully tested with 5 meters reading and displaying real-time data

## 📋 Known Limitations

### Current Constraints
- **Active Meter Limit**: 5 meters actively configured and operational (vs 32 theoretical maximum)
- **Server URLs**: Local/live API and OTA URLs are compile-time (`USE_LOCAL_SERVER`, `ampxportal_server_*`, `firmwareURL`); Gateway ID is Admin + NVS, not hardcoded after first boot
- **Admin Interface**: Gateway reboot + HTTP OTA (Check + Update) + Clear WiFi (ship-mode); Gateway ID change with password
- **Windows mDNS**: .local domain resolution not working on Windows (use IP address as workaround)
- **Live OTA binary**: Live `https://ampx.app/firmware/version.json` is **1.0.9** (v2 firmware). Sketch is **1.1.1** (v3). Next publish is **1.1.1** — do not publish 1.0.9 as the live update.
- **Live API key**: Live `/api/v3/` gated (401/201). `/api/v2/` still present for Influx 2.

### Technical Debt
- **HTML Templates**: Static meter sections (5 meters) in web files - need dynamic generation for scaling beyond 5
- **String Operations**: Some inefficient string concatenation in API functions
- **TCP `modbus_test_connection()`**: still a TCP open on port 502, not a Modbus PDU. Sep 28 it leaves the socket open for the sweep. Cable check lives in `meterTransportReady()`. RS485 test is still `return true`.
- **Error Recovery**: Basic retry logic, could be enhanced
- **Configuration Management**: Gateway ID via Admin/NVS; WiFi via WiFiManager; API/OTA URLs still compile-time
- **Documentation**: Some TODO comments indicate pending improvements

### Resolved Technical Debt
- ✅ **Global Variables**: Converted from hardcoded `m1_serial_number` variables to `meterSerialNumbers[]` array
- ✅ **Backend Scalability**: All backend functions use dynamic loops with `maxNumberOfMeters` constant
- ✅ **WebSocket Event Handler**: Fully implemented with proper connection tracking
- ✅ **WebSocket Performance**: Optimized with staggered meter reads - <3-second connections achieved (was 12-13 seconds)
- ✅ **Staggered Meter Reading**: Sequential 1-second intervals instead of batched 5-second reads
- ✅ **WebSocket Loop Servicing (July 2026)**: Restored `server.handleClient()` + `webSocket.loop()` before/after `handlePowerMeter()` — fixes multi-minute “Connecting…” when Modbus blocked handshakes
- ✅ **Boot discovery early-exit**: `detectNumberOfMeters()` breaks on first missing Modbus ID (contiguous 1..N)
- ✅ **NTP max wait**: tuned (~15s; exits early on success) after 5s proved too short
- ✅ **Local API E2E (July 2026)**: ESP → `http://{LAN_IP}/api/v2/` → InfluxDB → `ampx-app.local` portal View Data (gateway 100007 verified)
- ✅ **Live API E2E (July 2026)**: ESP → `https://ampx.app/api/v2/` → Influx → live portal Meters + View Data (100007 / SN 2724193004)
- ✅ **Live meters critical error**: Added `AMPX_INFLUXDB_*` to live `wp-config.php`; flushed OPcache; PHP 8.4 CSV/`str_getcsv` harden in portal plugin
- ✅ **HTTP Pull OTA (August 2026)**: Admin `POST /update` via `HTTPUpdate`; NVS last status; local E2E 1.0.1→1.0.2; ArduinoOTA left disabled
- ✅ **Shared API Key (August 2026)**: Local `X-AmpX-Api-Key` / `AMPX_API_KEY`; firmware `ampxportal_api_key` + 1.0.3; Postman/curl 401/201 verified
- ✅ **InfluxDB Cloud Serverless org (August 2026)**: AmpX / Energy Gateway / AWS Frankfurt (`eu-central-1-1.aws.cloud2.influxdata.com`)
- ✅ **API v3 local writes (August 2026)**: Isolated `/api/v3/` → Cloud Serverless; 201 + InfluxQL (`v3_plan_test`); v2 still 201 to `influxdb2.ampx.app`
- ✅ **Portal InfluxQL local reads (August 2026)**: Plugin 1.1.5; local `AMPX_INFLUXDB_*` → Cloud; CLI verified 100001 / SN-1234567890 and 100008 / v3_plan_test
- ✅ **Firmware local `/api/v3/` (August 2026)**: Sketch 1.1.0; USB 100007 Serial 201; local portal Cloud rows for 3423875005
- ✅ **Live Cloud cutover (August 2026)**: Live `/api/v3/` + plugin 1.1.5 + Cloud wp-config; firmware **1.1.1** on 100007; live Meter Data Cloud rows; example 100001 page HTML removed
- ✅ **Portal Meter Data UX (August 2026)**: Theme horizontal scroll (max-height viewport); plugin display 1000/30d with clear copy; server CSV export full 30d (`admin_post`); local verified gateway 100008
- ✅ **OTA reboot-loop fix (August 2026)**: 1.0.3 FreeRTOS HTTPS manifest task → LoadProhibited reboot loop; **1.0.4** manifest check on `loop()` only
- ✅ **Live HTTPS OTA (August 2026)**: 1.0.4/1.0.5 Check → `TG1WDT_SYS_RESET` (stack `WiFiClientSecure`); **1.0.7** static TLS client + 16KB loop stack + Check button + numeric version compare; live OTA on gateway 100008 Aug 18
- ✅ **Ship-mode / Clear WiFi (August 2026)**: Admin `POST /clear_wifi` + `ADMIN_PASSWORD`; `clearStoredWifi()` / `resetSettings()`; LEDs off before reboot (Clear WiFi and Admin Reboot); WiFiManager save-page next-step copy; sketch **1.0.9**
- ✅ **TCP/IP connection test (August 2026)**: `serviceMeters()` + `meterTransportReady()` (`LinkOFF` in sketch, not the AmpX TCP library); hardware verified 23 Aug; do not put `Ethernet.linkStatus()` in `ampx_modbus_tcpip.cpp`
- ✅ **TCP sweep socket + WS between registers (28 Sep 2026)**: one port-502 session per `handlePowerMeter()`; `webSocket.loop()` inside the register loop; per-register `delay(100)` removed. Bench before that pause was removed: Meter Details ~5 s (was up to ~40 s).
- ✅ **Meatrol frequency + power factor in the register map (28 Sep 2026)**: `frequency` 1024, `power_factor_L1`–`L3` 1052/1054/1056. No `power_factor_tot` (API v3 **400**s the whole post). `detectNumberOfMeters()` debug compares `MODBUS_TYPE`.
- ✅ **Live OTA catalog 1.2.1 (28 Sep 2026)**: `public_html/firmware/version.json` + `.bin`. Downloaded bin **1,335,296** bytes, ASCII **1.2.1**. Cloudflare cache rule **Bypass firmware OTA** (`/firmware/` bypass). Earlier the same day a cached **1.0.9** image was flashed while the status line said 1.2.1. Confirm Admin on **100007** shows **1.2.1**.

### Remaining Performance / Ops Notes
- Re-time Meter Details after the `delay(100)` removal (expected ~2 s faster than the 5 s measurement)
- Page copy says “a few seconds”; values still arrive together when `handleWebSocket()` runs after the sweep
- Update `ampxportal_server_local` when the PC LAN IP changes
- Ensure Windows Wi‑Fi profile Private + Apache firewall allow so ESP can reach PC:80
- Live portal: after editing `wp-config.php` on Hetzner, flush PHP OPcache (constants can look “missing” until then)
- Live debug: Debug Log Manager path in `WP_DEBUG_LOG`, not `wp-content/debug.log`
- Do not reintroduce FreeRTOS OTA / `WiFiClientSecure` side tasks, cross-core Arduino `String` caches, or a **local** `WiFiClientSecure` on `loop()`
- Do not publish OTA **1.0.9** (v2) or an S3 image at `ampx_open_energy_gateway.bin`. Live catalog is already single-url **1.2.1** because `fetchFirmwareManifest()` does not read `targets`. Chip-aware parse is still the plan: `memory-bank/plans/2026-08-23-multi-chip-ota.md`.
- Purge or bypass Cloudflare for `/firmware/` on every publish. Admin “OK: update applied (X)” is the manifest version, not the booted image.
- 100007 (TCP/IP, ME537 **3423875005**) showed real volts/amps on 26 Sep once the current coils were connected. Zeros before that were an unpowered meter, not the API.

## 🎯 Immediate Development Opportunities

### High Priority
1. **Confirm 100007 booted 1.2.1**, then frequency/PF on the live portal. Chip-aware `targets` parse is still unshipped. Do not publish 1.0.9 or an S3 `.bin` at the legacy URL.
2. **Migrate remaining live gateways** off `/api/v2/` (USB 1.2.0 after chip-aware firmware, not OTA 1.0.9)
3. **Deploy theme 1.0.9** (meter-data table scroll)
4. **Sunset v2 / Influx 2** after no gateway posts `/api/v2/`
5. **Scale to 10 Meters**: Add HTML sections for meters 6-10 (backend already supports this)
6. **Windows mDNS Resolution**: Troubleshoot and fix .local domain access on Windows

### Medium Priority
1. **Additional Meter Support**: Extend beyond Meatrol to other manufacturers
2. **Data Persistence**: Local data logging capabilities
4. **Alert System**: Email/SMS notifications for fault conditions

### Future Enhancements
1. **Historical Data**: Database integration for trend analysis
2. **Advanced Dashboard**: Charts and visualization capabilities
3. **Mobile App**: Native mobile application for remote monitoring
4. **Protocol Extensions**: Support for additional industrial protocols

## 🔧 System Health Assessment

### Strengths
- **Production Ready**: Stable codebase suitable for industrial deployment
- **Comprehensive**: Full feature set from hardware to cloud integration
- **Maintainable**: Clean modular architecture supports ongoing development
- **Documented**: Extensive inline documentation and comprehensive README
- **Power Supply Validated**: Resolved ESP32 reset issues, confirmed stable operation

### Performance Metrics
- **Update Frequency**: 3-second real-time updates
- **API Transmission**: 30-second intervals to remote server
- **Uptime Target**: 24-hour operation cycles with automatic recovery
- **Memory Usage**: Optimized for ESP32 platform constraints

### Deployment Status
- **Development**: Fully functional development environment
- **Testing**: Suitable for industrial testing and validation
- **Production**: Ready for commercial deployment with current feature set
- **Scaling**: Architecture supports horizontal scaling across multiple sites

## 📈 Success Metrics

### Achieved Targets
- ✅ Real-time meter communication
- ✅ Web interface functionality
- ✅ API integration working
- ✅ Multi-protocol support
- ✅ Automatic network configuration
- ✅ Industrial-grade reliability patterns

### Next Milestones
- 🎯 Confirm 100007 booted **1.2.1** (frequency/PF on the portal); then chip-aware `targets` parse
- 🎯 Sunset Influx 2 / `/api/v2/`
- 🎯 32-meter capacity utilization
- 🎯 Enhanced fault tolerance
- 🎯 Extended meter manufacturer support

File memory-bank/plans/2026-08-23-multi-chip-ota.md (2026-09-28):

# Multi-chip OTA — saved for later

**Date:** 2026-08-23  
**Status:** Designed; not implemented (except `CHIP_OTA_KEY` + `FIRMWARE_VERSION` `"1.2.0"` in the sketch)

Canonical copies (same decision):

- Spec: `D:\xampp\htdocs\ampx.app\docs\superpowers\specs\2026-08-23-multi-chip-ota-design.md`
- Plan: `D:\xampp\htdocs\ampx.app\docs\superpowers\plans\2026-08-23-multi-chip-ota.md`

## Do this next session

1. Finish chip-aware parse in `functions_ota.ino` (no `firmwareURL` fallback).
2. USB-flash **100007** with 1.2.0 **before** publishing live OTA.
3. Publish `targets`-only `version.json` + `firmware/esp32/*.bin`.
4. Do **not** publish 1.0.9 or a single-url 1.1.1 catalog.
5. Never put an S3 image at `https://ampx.app/firmware/ampx_open_energy_gateway.bin`.

S3 hardware port is a later task. OTA cannot migrate ESP32 → S3 silicon.

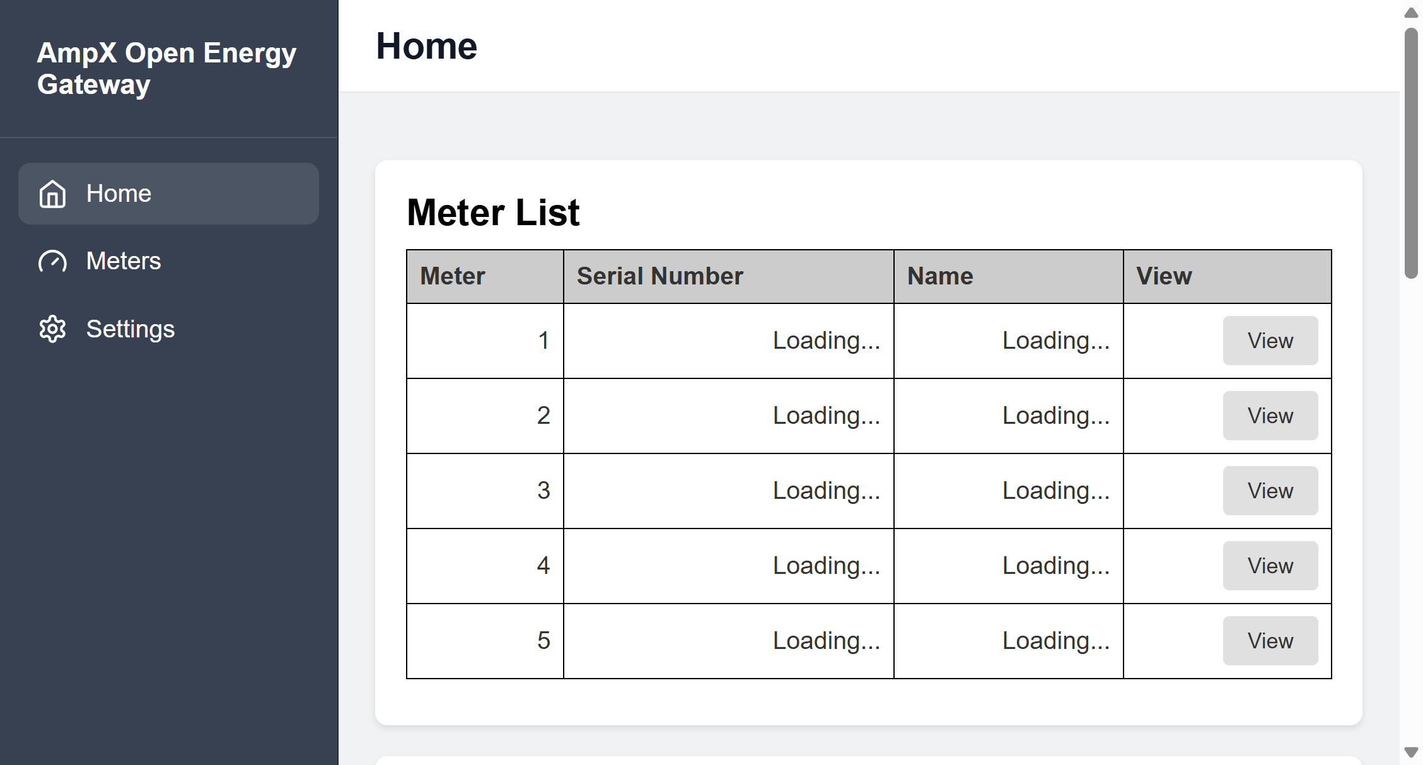
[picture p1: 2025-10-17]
.playwright-mcp/gateway-home-page.png

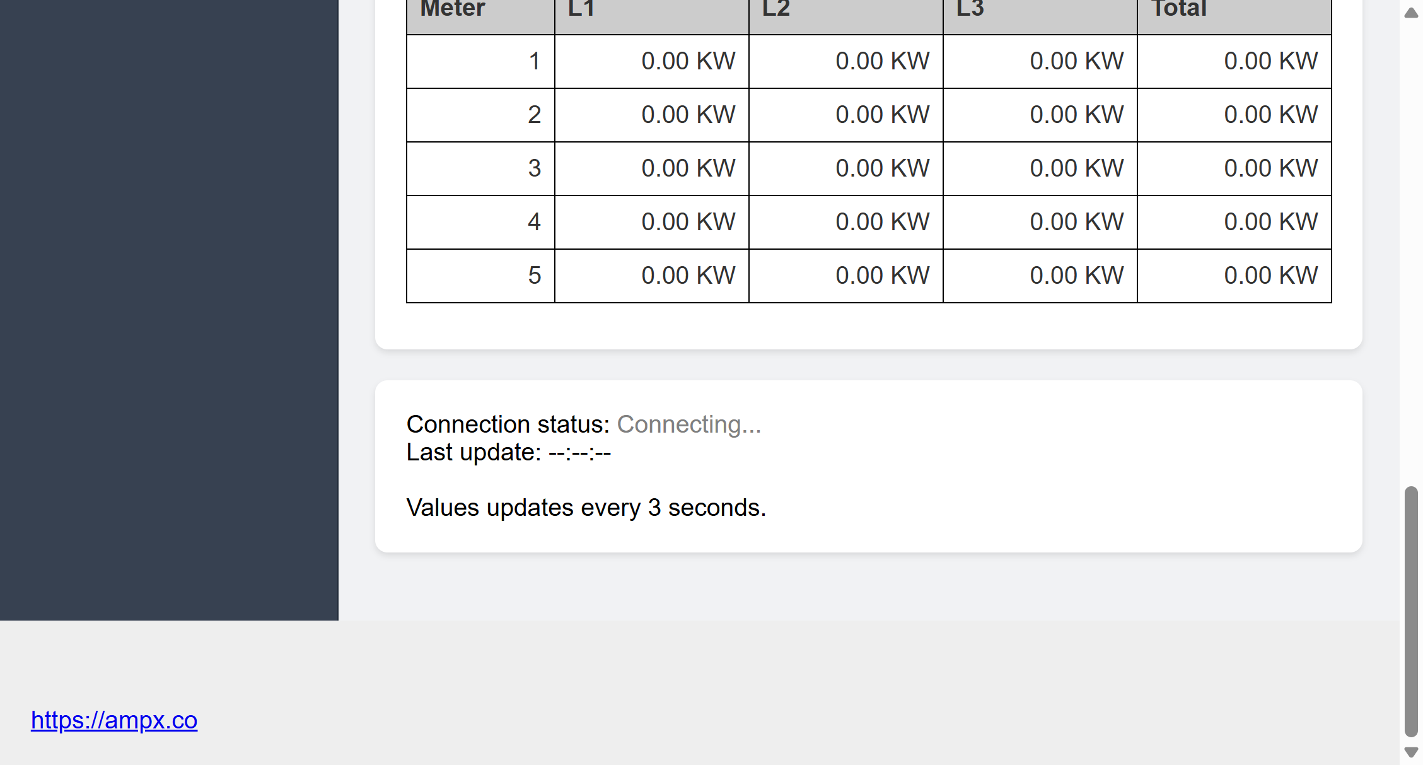
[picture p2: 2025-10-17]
.playwright-mcp/gateway-current-state.png

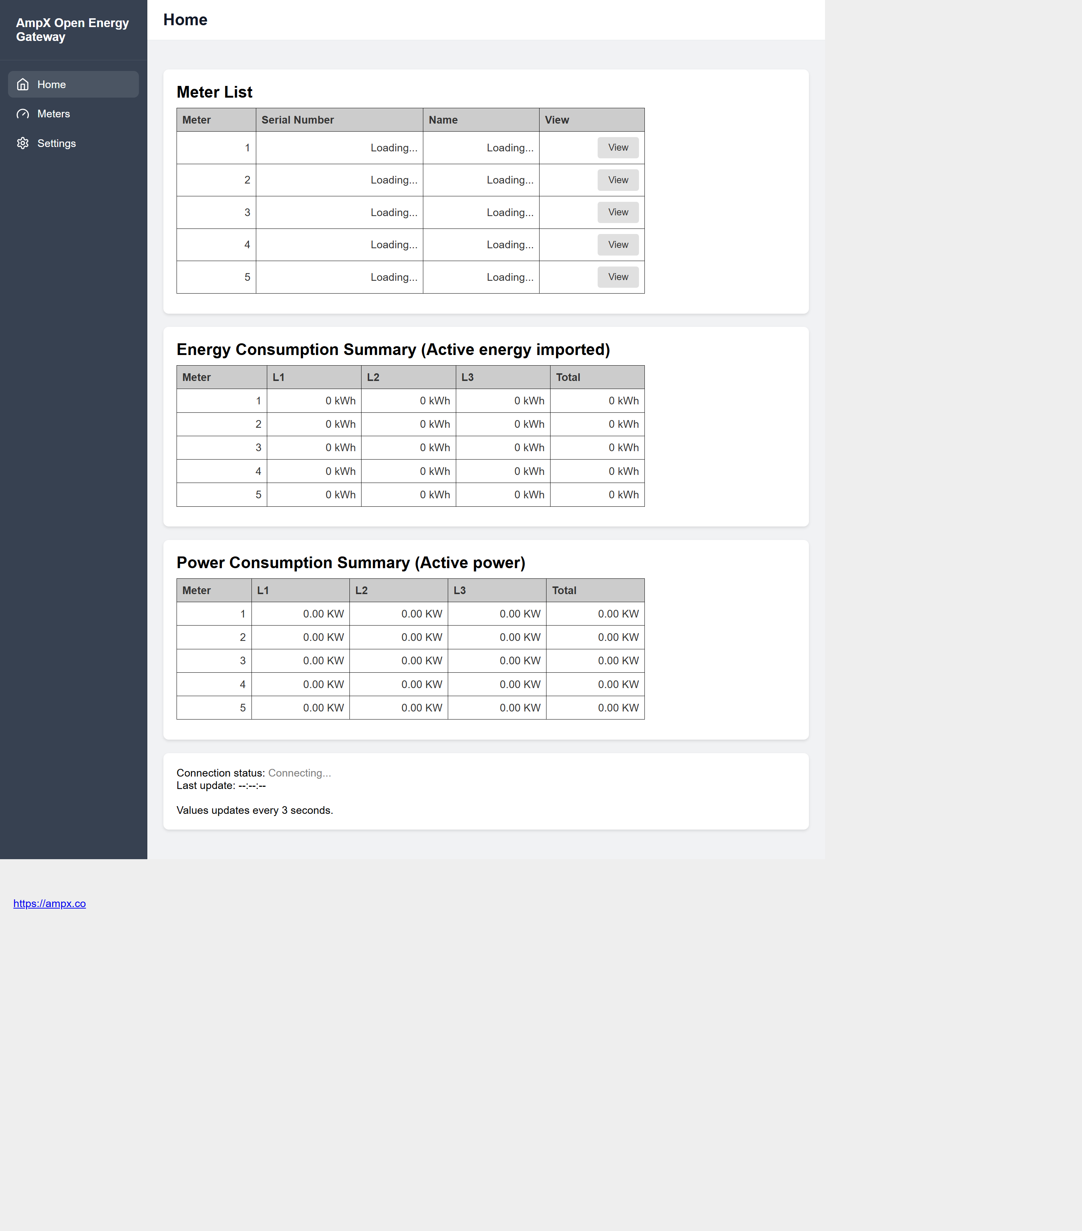
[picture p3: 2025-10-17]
.playwright-mcp/gateway-success.png

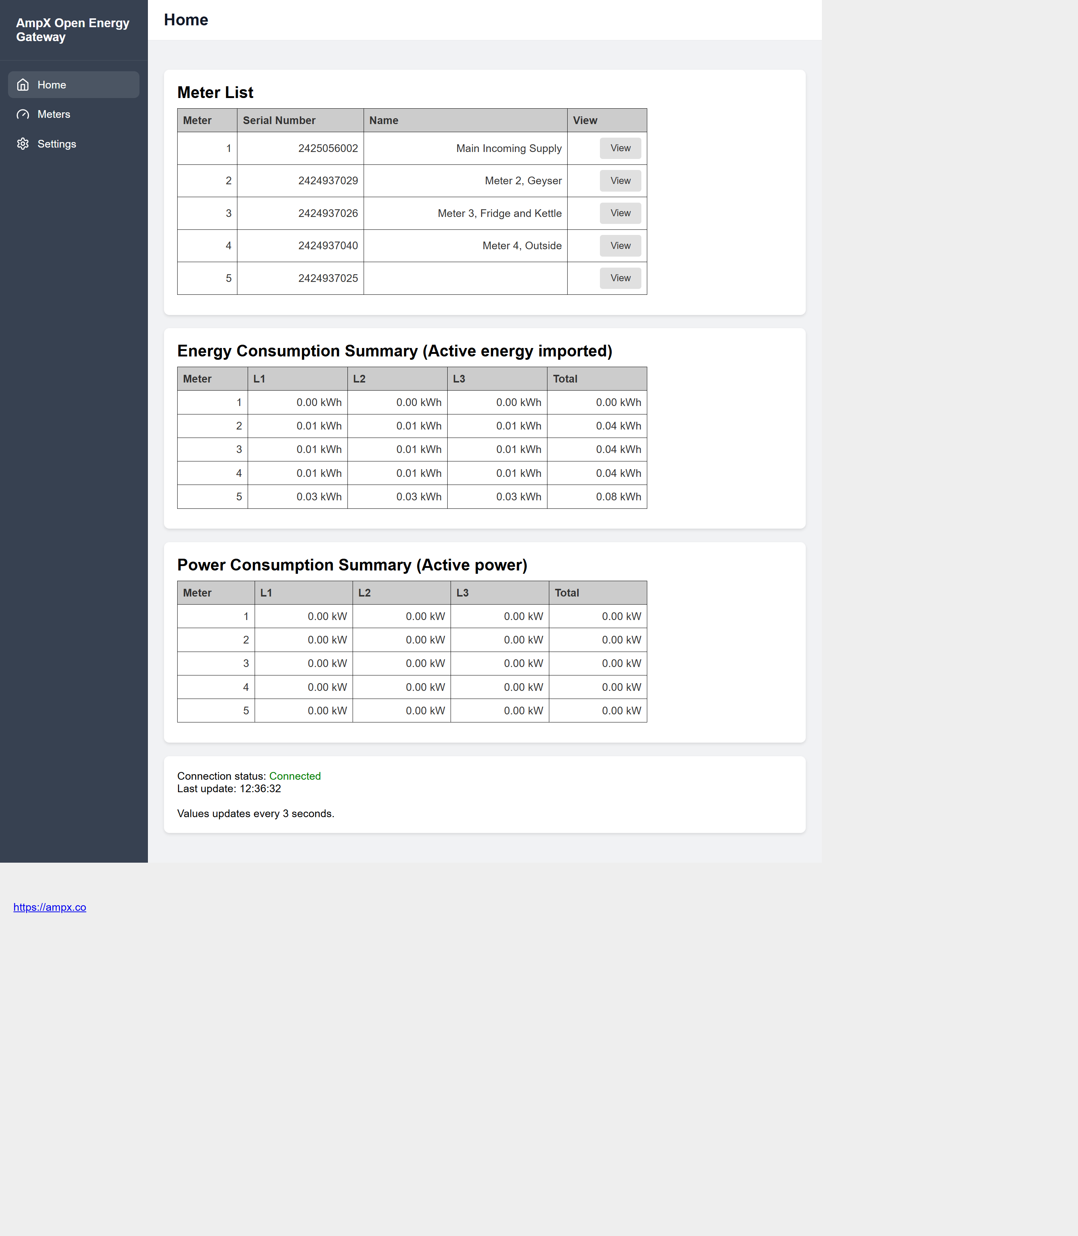
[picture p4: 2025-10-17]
.playwright-mcp/gateway-12sec-load.png

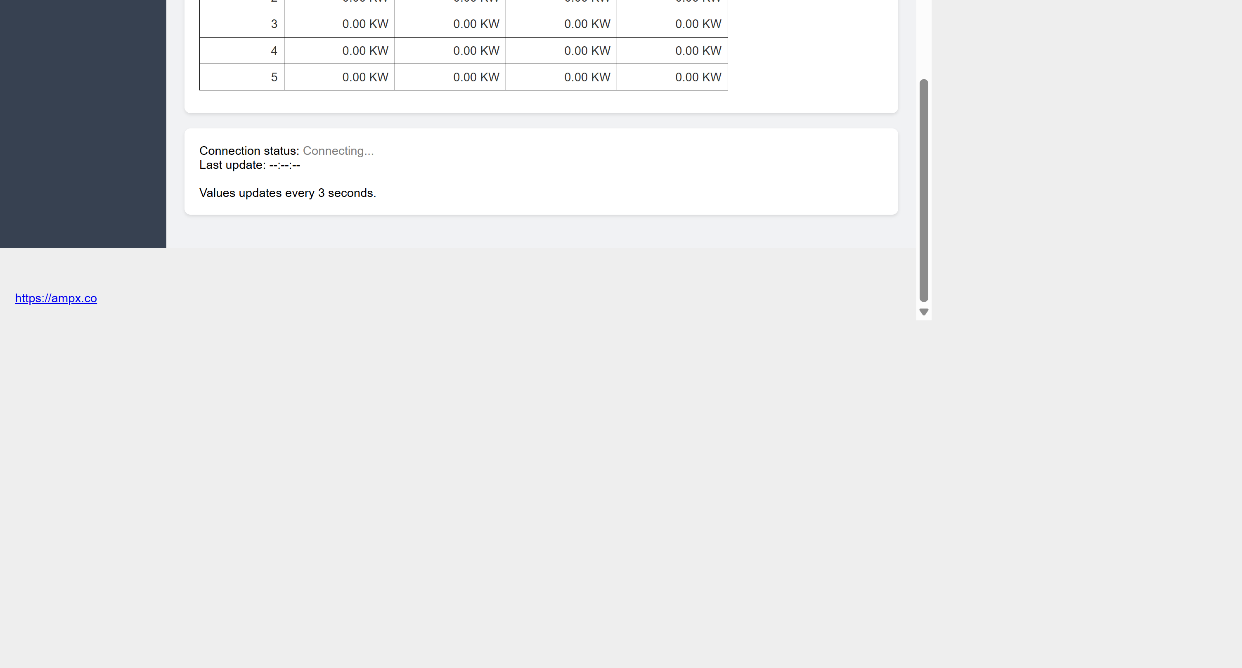
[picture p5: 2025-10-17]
.playwright-mcp/gateway-via-ip.png

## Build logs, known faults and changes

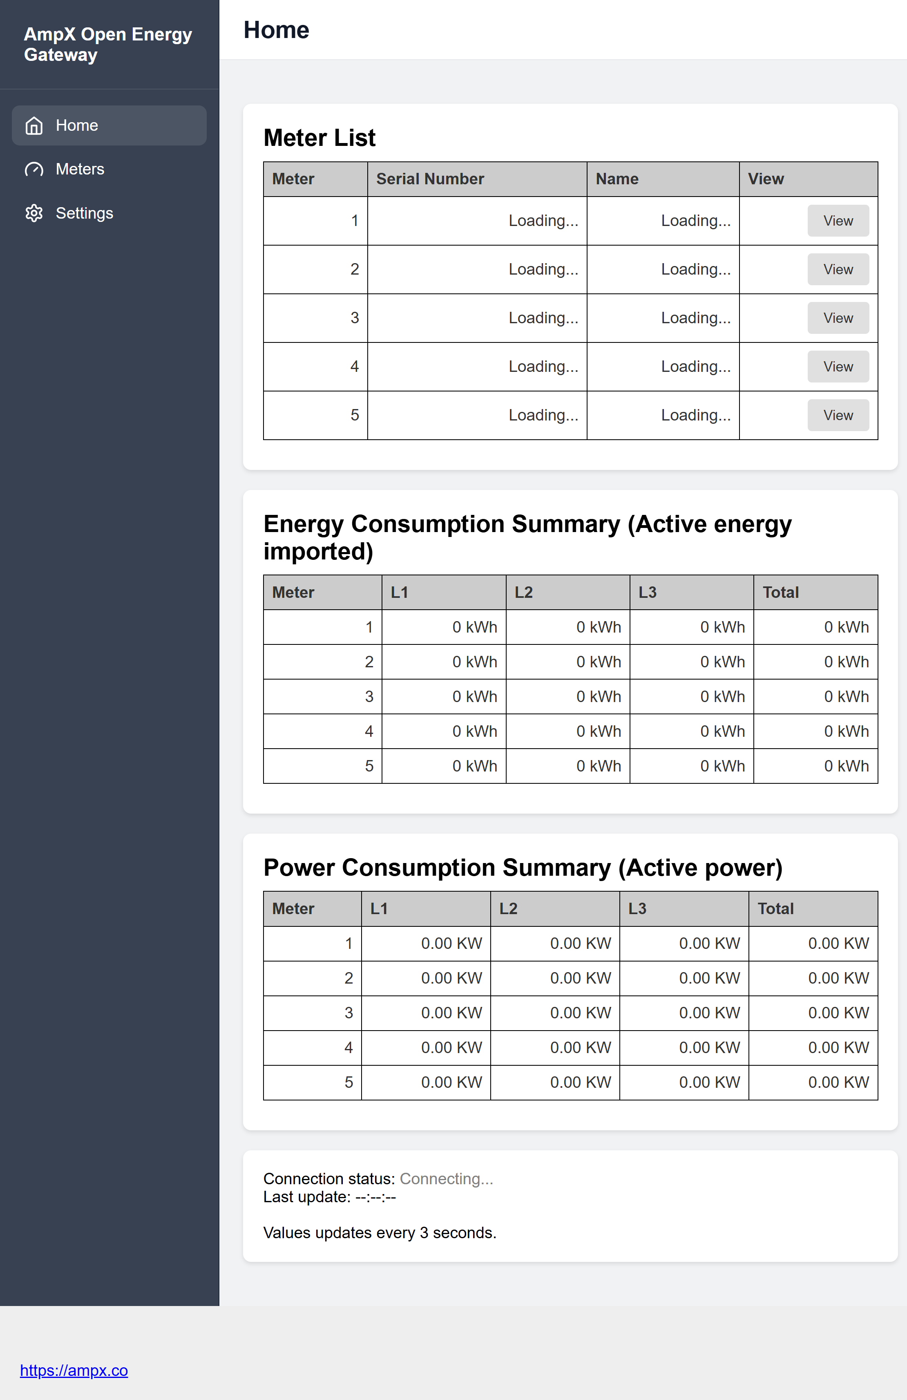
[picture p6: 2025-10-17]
.playwright-mcp/gateway-websocket-issue.png

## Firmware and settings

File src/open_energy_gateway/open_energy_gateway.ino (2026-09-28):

//Before compiling....
//1. Make sure the correct connection type is set for the gateway, either RS485 or TCPIP, MODBUS_TYPE
//2. Set the flash size correctly to 8MB
//3. Partition scheme: custom (partitions.csv — dual OTA app slots). Alternative: "8M with spiffs (3MB APP/1.5MB SPIFFS)"
//4. Set the API to use the local server or the remote server. #define USE_LOCAL_SERVER true or false
//5. Set debug to enabled or disabled. Disable for live to increase speed, but one also lose the debug info.
//6. Select the correct COM port, check by using the function "Get Board Info"
//7. Set the serial port baud rate to: 115200 baud.
//8. Select the correct board: "ESP32 Dev Module" (WROOM-32U / WROVER field units) or "ESP32S3 Dev Module" (S3-WROOM-1U bench port)
//   ESP32S3 Dev Module settings: USB CDC On Boot = Disabled (use the "UART" USB socket of the DevKitC-1U for flashing + monitor),
//   USB Mode = Hardware CDC and JTAG, Flash Size = 8MB or 16MB (match module: N8R8 / N16R8), PSRAM = OPI PSRAM (R8 modules),
//   Partition Scheme = Custom (sketch partitions.csv is picked up automatically), Flash Mode = QIO 80MHz, Upload Speed 921600.
//   First flash of a new S3 board: Tools -> Erase All Flash Before Sketch Upload = Enabled, then set it back to Disabled.
//   Pin map is selected automatically from the board (CONFIG_IDF_TARGET_*) - see "Board pin map" below.
//9. OTA: Admin pulls https://ampx.app/firmware/ampx_open_energy_gateway.bin (first flash via USB with OTA partitions)
//   An S3 build must never be published at that single URL - S3 images go under targets.esp32s3 in version.json (see CHIP_OTA_KEY).


//There will be two variants of this gateway, one working with Modbus over RS485 and the other
//working with mobus over TCP/IP, this is setup here and used depeding on what is needed.
#define MODBUS_TYPE_RS485 1
#define MODBUS_TYPE_TCPIP 2
//Set the required Modbus type variant here to either RS485 or TCPIP
//In other words, change this depending on if the board is for RS485 or for TCPIP
//For TCPIP use MODBUS_TYPE_TCPIP, for RS485 use MODBUS_TYPE_RS485
#define MODBUS_TYPE MODBUS_TYPE_TCPIP

//NB, Also remember to change the API server from local to live if needed...

// Bump when publishing a new .bin to ampx.app/firmware/
#define FIRMWARE_VERSION "1.2.2"
//To publish OTA for gateways in the field
//Bump FIRMWARE_VERSION
//Use Sketch → Export compiled Binary (not the Upload / play button)
//FTP Copy that .bin into ampx.app\firmware\ as ampx_open_energy_gateway.bin
//Update version.json in that same folder and deploy

// OTA catalog key must match targets.<chip> in firmware/version.json.
// Derived from the board you compiled for so an ESP32 build never downloads an S3 image (and the reverse).
#if CONFIG_IDF_TARGET_ESP32S3
#define CHIP_OTA_KEY "esp32s3"
#elif CONFIG_IDF_TARGET_ESP32
#define CHIP_OTA_KEY "esp32"
#else
#error "Unsupported chip for OTA; add CHIP_OTA_KEY"
#endif

//Defining custom partiotions.
//Custom partitions is defined in the file partitions.csv
//This file can be edited using the online tool: https://thelastoutpostworkshop.github.io/ESP32PartitionBuilder/
//https://www.youtube.com/watch?v=EuHxodrye6E


//Unique Gateway ID for each gateway manufactured. To be used when adding it to a the portal under a specific user.
//This is set when manufactured and will be unique for each gateway.
//Format: 100001 increment.

//Default value - can be changed via admin web interface
#define DEFAULT_GATEWAY_ID 100001

//Global variable to store the current gateway ID (loaded from NVS)
int GATEWAY_ID = DEFAULT_GATEWAY_ID;
const char* ADMIN_PASSWORD = "1000";

/*
The following .ino files should be in the same directory as this main .ino file (AmpX-Energy-Gateway.ino).
  ampx_functions.ino
  ampx_functions_modbus.ino
  ampx_functions_network.ino
  ampx_functions_web.ino

These files are automatically included and merged with this main .ino file.
This just seperates all the functions and make this file easier to read.


For The ESP32 Node32s board do the following:
Go to File -> Preferences.
in the "Additional Boards Manager URLs"
Add the following String:
https://raw.githubusercontent.com/espressif/arduino-esp32/gh-pages/package_esp32_index.json

Then in the boards manager, search for: "esp32 by Espressif Systems"
Then install the board manager.

Now select the port and then 
Select "node32s" under the boards.

HTTP OTA (Admin): downloads ampx_open_energy_gateway.bin from ampx.app/firmware/
Requires dual-app OTA partitions (this sketch uses custom partitions.csv on 8MB flash).

ESP Board to be selected in Arduino IDE:
for ESP32-WROOM-32U - DUBEUYEW
  node32S
  Partition: 4MB (OTA not supported in this pass)
for ESP32-WROVER-IE-N8R8-DEVKITC-VE Espressif / 8MB modules
  ESP32 Dev Module
  Flash Size: 8MB
  Partition: custom (partitions.csv) or "8M with spiffs (3MB APP/1.5MB SPIFFS)"
*/
//Required to communicate with the RS485 Controller.
#include <HardwareSerial.h>

//Used to connect to the local WiFi network, Built-in library that comes with the ESP32 Arduino core
#include <WiFi.h>

//Install the library by tzapu, https://github.com/tzapu/WiFiManager, https://www.youtube.com/watch?v=Errh7LEEug0
#include <WiFiManager.h> //This is used to dymanically configure the wifi connection .


//ESP32 Multicast DNS (mDNS) library for ESP32.
//Built into the ESP32 Arduino core, so you don't need to install it separately from the Library Manager
//https://github.com/espressif/arduino-esp32/tree/master/libraries/ESPmDNS
#include <ESPmDNS.h>

// HTTP pull OTA (Admin). ArduinoOTA intentionally disabled to save flash.
#include <Update.h>
#include <HTTPUpdate.h>
#include <WiFiClientSecure.h>

// Arduino loop() defaults to 8KB. HTTPS (mbedTLS) plus HTTPClient on that task
// overflowed the stack and caused TG1WDT_SYS_RESET during OTA manifest fetch.
SET_LOOP_TASK_STACK_SIZE(16384);

//Time library for NTP synchronization
#include <time.h>

//Search for Preferences, Install the one by Vlodomyr Shymanskyy, https://github.com/vshymanskyy/Preferences
//Tested and working with version 2.1.0
//NVS  Non-Volatile Storage (Local Permanent Storage)
#include <Preferences.h>

//Creates a web server and serves a webpage with all the meter readings and settings.
#include <WebServer.h>

//Search for Arduino Websockets, install the one WebSockets by Markus Sattler
//Is the ESP Async WebServer@3.8.1 not maybe a better option - JF
#include <WebSocketsServer.h>
//Tested on version 2.7.1

//Search for ArduinoJson, install the one by Benoit Blanchon
#include <ArduinoJson.h>

//Built-in ESP32 library that provides HTTP client functionality for making HTTP requests to web servers and APIs.
#include <HTTPClient.h>

//SPIFFS SPI Flash File System, this is used to store the web pages in the flash memory of the ESP32.
//This adds about 30% to the 1MB program file but moves and loads the html files from the SPIFFS memomory
//#include "SPIFFS.h"

//The HTML code for the webpages are stored in a seperate file, this makes the code easier to read.
#include "web_home.h" 
#include "web_settings.h" 
#include "web_admin.h" 
#include "web_meters.h" 
#include "web_inc_header.h" 

//Define the meter registers and datatypes here in json format.
#include "meter_registers.h"





//This is an easy way to exclude all serial.print commands from production code to reduce the file size.
//Change this varialbe to enable or disable debugging
#define DEBUG 1

#if DEBUG == 1
  #define debug(x) Serial.print(x)
  #define debugln(x) Serial.println(x)
#else
  #define debug(x)
  #define debugln(x)
#endif




//=====================================================================================
// Board pin map - selected by the chip you compile for (Tools -> Board).
//   ESP32    : "ESP32 Dev Module"   -> ESP32-WROOM-32U / ESP32-WROVER-IE DevKitC (V2 PCB, field units)
//   ESP32-S3 : "ESP32S3 Dev Module" -> ESP32-S3-WROOM-1U DevKitC-1U (bench port, Sep 2026)
// Same sketch, same OTA catalog key logic (CHIP_OTA_KEY above). Do not mix the two maps.
//=====================================================================================
#if CONFIG_IDF_TARGET_ESP32S3
  // ESP32-S3-DevKitC-1U. Avoid: 0/3/45/46 (strapping), 19/20 (USB), 26-32 (flash),
  // 35/36/37 (octal PSRAM on N8R8/N16R8), 38 and 48 (on-board RGB LED on v1.1 / v1.0), 43/44 (UART0).
  // Status LEDs - all on the J1 header side, contiguous, so one 6-way ribbon (5 LED + GND) reaches the front board.
  #define LED_1_POWER     4
  #define LED_2_METER     5
  #define LED_3_WIFI      6
  #define LED_4_INTERNET  7
  #define LED_5_SERVER    15
  // W5500 / W5500-Lite on FSPI (the S3 default SPI pins: SCK 12, MISO 13, MOSI 11, SS 10)
  #define ETH_SPI_SCK_PIN   12  // Yellow
  #define ETH_SPI_MISO_PIN  13  // Orange
  #define ETH_SPI_MOSI_PIN  11  // Blue
  #define ETH_SPI_SCS_PIN   10  // Green  (nSS on the module)
  //#define ETH_SPI_RST_PIN 14  // Optional: module RST. Leave COMMENTED OUT unless RST is physically wired -
                                // defining it makes initEthernet() pulse the pin. The W5500 has its own pull-up.
  // RS485 (MAX485) - UART1. Reserved now so the combined RS485+Ethernet board needs no re-pinning.
  #define MAX485_DE       16  // White
  #define MAX485_RE_NEG   16
  #define RX_PIN          18  // RO Orange
  #define TX_PIN          17  // DI Yellow
#else
  // Classic ESP32 (ESP32-WROOM-32U / WROVER DevKitC) - unchanged field pin map.
  #define LED_1_POWER     12 //Indicates Power is on
  #define LED_2_METER     14 //Indicates Meter is connected via Modbus
  #define LED_3_WIFI      27 //Indicates WiFi is connected
  #define LED_4_INTERNET  26 //Indicates Internet is connected, this is the green LED
  #define LED_5_SERVER    25 //Indicates succesfull communication with the Server
  // W5500 on VSPI (hardware SPI default pins: SCK 18, MISO 19, MOSI 23)
  #define ETH_SPI_SCK_PIN   18  // Yellow
  #define ETH_SPI_MISO_PIN  19  // Orange
  #define ETH_SPI_MOSI_PIN  23  // Blue
  #define ETH_SPI_SCS_PIN   5   // Green  (nSS on the module)
  // RS485 (MAX485)
  #define MAX485_DE       4   // White
  #define MAX485_RE_NEG   4
  #define RX_PIN          16  // RO Orange
  #define TX_PIN          17  // DI Yellow
#endif
//Modbus A, Positive, Green.  Modbus B, Negative, Blue.  W5500: Red VCC 3V3, Black GND.


//Include AmpX custom written libraries for Modbus
//Saved in the D:\OneDrive\JF Data\UserData\Documents\Arduino\libraries folder
#if MODBUS_TYPE == MODBUS_TYPE_RS485

  //Custom written AmpX Modbus library for RS485
  //Saved in libary folder. On my pc:
  //On Windows: D:\OneDrive\JF Data\UserData\Documents\Arduino\libraries\ampx_modbus_rs485\src\ampx_modbus_rs485.cpp
  //On Linux: /home/username/Arduino/libraries/ampx_modbus_tcpip-main/src
  #include <ampx_modbus_rs485.h>
  // RS485 pins: see board pin map above (MAX485_DE / MAX485_RE_NEG / RX_PIN / TX_PIN)

#else

  //Custom written AmpX Modbus library for TCPIP
  //Saved in libary folder. On my pc: D:\OneDrive\JF Data\UserData\Documents\Arduino\libraries\ampx_modbus_tcpip\src\ampx_modbus_tcpip.cpp
  #include <ampx_modbus_tcpip.h>
  #include <SPI.h>
  // Ethernet pins: see board pin map above (ETH_SPI_*). SPI.begin(SCK, MISO, MOSI, CS) is called
  // explicitly in initEthernet() so the bus pins are the same on every board, not whatever the core's default is.

  //Define Ethernet Settings, Mac and IPs
  byte mac[] = {0x90, 0xA2, 0xDA, 0x0E, 0x94, 0xB5};
  //IPAddress pc_ip(192, 168, 1, 32);   // PC IP, Assign a static IP to your PC and change it here to be the same.
  IPAddress ip(192, 168, 1, 50);     // Arduino IP
  IPAddress gateway(192, 168, 1, 1);  // Network gateway
  IPAddress subnet(255, 255, 255, 0); // Subnet mask
  IPAddress meter_ip(192, 168, 1, 55); // Energy meter IP
  //IPAddress meter_ip(192, 168, 2, 122); // Energy meter IP
#endif


//Status LED pins: see board pin map above (LED_1_POWER .. LED_5_SERVER).


//Constant data types, used in the processRegisters function.
//These are now defined in meter_registers.h
//const int dataTypeInt32 = 1;
//const int dataTypeInt64 = 2;
//const int dataTypeFloat = 3;

//NVS  Non-Volatile Storage (Local Permanent Storage)
Preferences preferences;

//Web server and websocket
#define HTTP 80
WebServer server(HTTP);
WebSocketsServer webSocket = WebSocketsServer(81);


//TODO: Improve this code use an array and do not use strings.
/*
String m1_serial_number = "";  // Meter one serial number
String m2_serial_number = "";
String m3_serial_number = "";
String m4_serial_number = "";  
*/

int numberOfMeters = 0;  // Number of meters connected, this will automatically be updated based on the number of meters detected
const int maxNumberOfMeters = 10;  // Maximum number of meters supported, this is used to limit the number of meters that can be displayed on the web page.
String meterSerialNumbers[maxNumberOfMeters]; // Array to store the serial numbers of the meters.
int currentMeterIndex = 1;  // Track which meter to read next (for staggered reading)




//The JsonDocument is used to send data to the websocket....
//StaticJsonDocument<512> JsonDoc;          //Define optimized JSON documents with minimum required size. StaticJsonDocument allocates memory on the stack (fixed at compile time)
DynamicJsonDocument JsonDoc(2048);        //DynamicJsonDocument allocates memory on the heap (dynamic at runtime)

//JSON document for meter register definitions
JsonDocument MeterRegisterDefs;

bool readSerial = false;
bool onBoot = true; //this is used to check if the device the first time it starts up, used in the loop to send read and send data immediately.


//EMONCMS, Remote energy logging, https://JsonDocs.openenergymonitor.org/emoncms/index.html
//TODO This needs to be removed, can forward to other portal from ampx portal
/*Commented out to save space
const char* emoncms_server = "http://emoncms.org";
const char* api_key = "c0526f06893d1063800d3bb966927711"; //your_API_KEY
*/

//AmpX Energy Portal, Remote energy logging. Use IP address of the server if using local server(no dns server).
// LAN IP of PC running XAMPP (port 80). Do not use :8080 unless Docker API is running.
// Note: https://ampx.app is the public site; local vhost is ampx-app.local (ESP should use IP).
const char* ampxportal_server_local = "http://192.168.2.120/api/v3/";
const char* ampxportal_server_live = "https://ampx.app/api/v3/";
// Both local and live URLs are /api/v3/ (Cloud Serverless). /api/v2/ remains on Hetzner for Influx 2 until sunset.

// Shared secret for AmpX Portal API (header X-AmpX-Api-Key). Must match AMPX_API_KEY in api/config/config.php.
const char* ampxportal_api_key = "b9e96dfb8f9c722b917f1c536ec67c373e5644eee75f267dce94b7294f0274b7";

// Which API to use local or live? - set to true for local development, false for live
#define USE_LOCAL_SERVER false

// Firmware OTA hosting (same local/live switch as API)
#if USE_LOCAL_SERVER
const char* firmwareURL = "http://192.168.2.120/firmware/ampx_open_energy_gateway.bin";
const char* firmwareManifestURL = "http://192.168.2.120/firmware/version.json";
#else
const char* firmwareURL = "https://ampx.app/firmware/ampx_open_energy_gateway.bin";
const char* firmwareManifestURL = "https://ampx.app/firmware/version.json";
#endif

struct FirmwareManifest {
  bool ok = false;
  String version;
  String url;
  String error;
};

// Cached OTA status — filled in loop(), never via HTTPClient inside a WebServer handler.
// Do not fetch from a FreeRTOS side task: WiFiClientSecure + Arduino String across cores
// caused LoadProhibited / corrupted backtrace reboot loops on 1.0.3.
struct OtaStatusCache {
  bool ready = false;
  bool ok = false;
  String available = "Not checked yet";
  String status = "Not checked yet";
  bool upToDate = false;
  bool updateAvailable = false;
  String error = "";
};
OtaStatusCache otaStatusCache;
// Only GET /ota_status?refresh (Check for update) requests a check — not Admin page load, not boot.
volatile bool otaManifestCheckRequested = false;
unsigned long otaManifestLastCheckMs = 0;

//Function prototypes, it needs to be here because it is used in the setup function.
//one needs to add a forward declaration for this function as well, as it is defined in a seperate .ino file:functions.ino
void handlePowerMeter(int meterNumber);
void postToAmpXPortal2(int meterNumber);
void setupMeterRegisters();
void detectNumberOfMeters();
void handleWebSocket();
void webSocketEvent(uint8_t num, WStype_t type, uint8_t * payload, size_t length);
void initNTP();
String getCurrentTimestamp();
void loadGatewayId();
void saveGatewayId(int newGatewayId);
void handleUpdateGatewayId();
void handleUpdate();
void handleAdmin();
void handleOtaStatus();
void initmDNS();
void initOTA();
bool doOTAUpdate();
void saveOtaStatus(const String& status);
String getOtaStatusText();
String getOtaTimeText();
bool fetchFirmwareManifest(FirmwareManifest& out);
bool isNewerVersion(const String& serverVer, const String& deviceVer);
void serviceOtaManifestCheck();
void requestOtaManifestCheck();
void handleClearWifi();
void clearStoredWifi();
void serviceMeters();
#if MODBUS_TYPE == MODBUS_TYPE_TCPIP
void serviceNetworkWhileModbusWaits();
#endif


void setup() {
  // initialize LED status pins as outputs.
  pinMode(LED_1_POWER, OUTPUT);
  pinMode(LED_2_METER, OUTPUT);
  pinMode(LED_3_WIFI, OUTPUT);
  pinMode(LED_4_INTERNET, OUTPUT);
  pinMode(LED_5_SERVER, OUTPUT);

  //Indicate that the power is on with a LED
  digitalWrite(LED_1_POWER, HIGH);
  //Turn off all the other LEDs (It could happen that the LED got stuck on the on state after last reset).
  digitalWrite(LED_2_METER, LOW);
  digitalWrite(LED_3_WIFI, LOW);
  digitalWrite(LED_4_INTERNET, LOW);
  digitalWrite(LED_5_SERVER, LOW);


  Serial.begin(115200); // Debug serial
  while (!Serial) {
    delay(10); // Wait for serial port to become ready.
  }
  delay(1200); //Wait some more for the serial port to become ready...
                //1200 Ok, but increase if debugging and resetting by cycling the power.
  debugln("Serial port ready. Begin setup...");
  debug("Firmware version: ");
  debugln(FIRMWARE_VERSION);

  
  // Initialize NVS  Non-Volatile Storage (Local Permanent Storage)
  initNvs();  

  // Load gateway ID from NVS storage
  loadGatewayId();
  
  // Debuging information
  debug("GATEWAY_ID: ");
  debugln(GATEWAY_ID);

  //Depending on the Modbus type set, initialise either RS485 or TCPIP
  #if MODBUS_TYPE == MODBUS_TYPE_RS485
    initRS485(&Serial1, RX_PIN, TX_PIN);
    debugln("RS485 Modbus initialized");
  #else
    initEthernet();
    debugln("TCPIP Modbus initialized");
  #endif
  
  Serial.println("Setup complete. Starting communication...");
  
  // Initialize WiFi
  initWiFi(); //Program will not continue unless WiFi is connected..

  // Initialize mDNS for .local domain access
  initmDNS();

  // Initialize NTP time synchronization (must be after WiFi)
  initNTP();

  //Initialise the local web server.
  initServer();

#if MODBUS_TYPE == MODBUS_TYPE_TCPIP
  // Meter reads wait up to 2s. Service HTTP/WebSocket during that wait.
  modbus_set_idle_callback(serviceNetworkWhileModbusWaits);
#endif

  // Initialize meter register definitions
  setupMeterRegisters();

  //Detect number of meters and set global variable, numberOfMeters.
  detectNumberOfMeters();

  // OTA: manifest checks run in loop() when Admin requests them (see serviceOtaManifestCheck).
  //initOTA();
}

void loop() {
  //JF commented out to reduce size
  //ArduinoOTA.handle();

  static unsigned long counter1 = 0;
  static unsigned long counter2 = 0;
  static unsigned long counter3 = 0;
  
  //Interval to test the meter connection and read the parameters, and update the local web page.
  const unsigned long METER_CONNECTION_INTERVAL = 1000;    // 1 second (staggered reading: 5 meters × 1s = 5s cycle)
  //Interval to post the meter data to the remote server
  const unsigned long REMOTE_SERVER_INTERVAL = 30000;    // 30 seconds
  //Interval to reboot the ESP32
  const unsigned long REBOOT_INTERVAL = 86400000;    // 24 hours

  //Built-in Arduino function that returns the number of milliseconds since the Arduino board began running the current program.
  unsigned long now = millis();

  //Test meter connection and read the parameters every METER_CONNECTION_INTERVAL milliseconds
  //If onBoot is true, read and send data immediately on boot.
  if (onBoot == true || now - counter1 > METER_CONNECTION_INTERVAL) {
    onBoot = false;
    serviceMeters();
    counter1 = now;
  }
 

  // Post meter data to remote server every 5 minutes, 300000
  //TODO: JF 2025-06-08 for testing, i decreased it to 30 seconds (30000).
  if (now - counter2 > REMOTE_SERVER_INTERVAL) {
    //Post meter data to remote server
    for (int i = 1; i <= numberOfMeters; i++) {
      //postToEmonCMS(i);
      postToAmpXPortal2(i);
    }
    counter2 = now;
  }

  //Reboot every 24 hours to ensure it keeps working, 86400000
  if (now - counter3 > REBOOT_INTERVAL) {
    //Reboot the ESP32
    //ESP.restart();
    counter3 = now;
  }


  // OTA manifest refresh on loop task (same core as WebServer) — avoids cross-core String/HTTPS crashes.
  serviceOtaManifestCheck();

  //These functions must run continuesly, so one can not include a delay in the main loop.
  server.handleClient();  //Handle webserver requests from client
  webSocket.loop();       //Handle websocket requests from client
}

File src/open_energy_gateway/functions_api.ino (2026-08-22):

//API to post data to the AmpX Portal and EmonCMS

//Post data to the AmpX Portal API (local /api/v3/ or live /api/v2/)
void postToAmpXPortal2(int meterNumber = 1) {
    debugln("postToAmpXPortal2 function called");
  
    String meterPrefix = "m" + String(meterNumber) + "_";
    
    // Get current timestamp in ISO 8601 format
    String timestamp = getCurrentTimestamp();
  
    //For debugging and testing, comment out the getCurrentTimestamp function and use the following code.
    //Create timestamp in ISO 8601 format
    /*
    unsigned long seconds = millis() / 1000;
    unsigned long hours = (seconds / 3600) % 24;
    unsigned long minutes = (seconds / 60) % 60;
    unsigned long secs = seconds % 60;
    
    String timestamp = "2025-01-28T";
    if (hours < 10) timestamp += "0";
    timestamp += String(hours) + ":";
    if (minutes < 10) timestamp += "0";
    timestamp += String(minutes) + ":";
    if (secs < 10) timestamp += "0";
    timestamp += String(secs) + "Z";
    */
    
    // Determine serial number for this meter (API v2 requires non-empty serial_number)
    String serialNumber = "";
    if (meterNumber >= 1 && meterNumber <= maxNumberOfMeters) {
      serialNumber = meterSerialNumbers[meterNumber - 1];
    }
    serialNumber.trim();

    if (serialNumber.length() == 0) {
      JsonVariant serialVar = JsonDoc[meterPrefix + "serial_number"];
      if (!serialVar.isNull()) {
        serialNumber = serialVar.as<String>();
        serialNumber.trim();
      }
    }

    // Numeric fallback when Modbus has not filled a serial yet (meter 1 -> "10000001", meter 2 -> "10000002", ...)
    const unsigned long kFallbackSerialBase = 10000000UL;
    if (serialNumber.length() == 0) {
      serialNumber = String(kFallbackSerialBase + (unsigned long) meterNumber);
      debugln("[WARN] Meter serial not read; using fallback serial_number: " + serialNumber);
    }

    // Start building the JSON manually for Docker API format
    String httpRequestData = "{";
    httpRequestData += "\"gateway_id\":\"" + String(GATEWAY_ID) + "\",";
    httpRequestData += "\"meter_id\":\"" + String(meterNumber) + "\",";
    httpRequestData += "\"serial_number\":\"" + serialNumber + "\",";
    httpRequestData += "\"timestamp\":\"" + timestamp + "\",";
    httpRequestData += "\"values\":{";
    
    // Add all meter readings from JsonDoc to the values object
    bool firstValue = true;
    for (JsonPair kv : JsonDoc.as<JsonObject>()) {
      String key = kv.key().c_str();
      // Only include readings for this meter (starts with correct prefix)
      if (key.startsWith(meterPrefix)) {
        if (key.endsWith("_name") || key.endsWith("_serial_number")) {
          continue;
        }
        String value = kv.value().as<String>();
        if (!firstValue) {
          httpRequestData += ",";
        }
        httpRequestData += "\"" + key + "\":" + value;
        firstValue = false;
      }
    }
    
    httpRequestData += "}}"; // Close values object and main object
    
    // Debug: Print the JSON payload and URL
    debugln("[DEBUG] JSON payload to be sent:");
    debugln(httpRequestData);

    String url = "";
    if (USE_LOCAL_SERVER) {
      url = String(ampxportal_server_local);
    } else {
      url = String(ampxportal_server_live);
    }
    debugln("[DEBUG] Target URL:");
    debugln("URL: " + url);
  
    if (WiFi.status() == WL_CONNECTED) {
      HTTPClient http;   
      http.begin(url);
      http.addHeader("Content-Type", "application/json");
      http.addHeader("X-AmpX-Api-Key", ampxportal_api_key);
    
      // Send HTTP POST request
      int httpResponseCode = http.POST(httpRequestData);
  
      // Debug: Print HTTP response code and response body
      String response = http.getString();
      debug("[DEBUG] HTTP Response Code: ");
      debugln(httpResponseCode);
      debug("[DEBUG] HTTP Response Body: ");
      debugln(response);
  
      // Check the response code
      if (httpResponseCode == 201) {
        debugln("✅ SUCCESS: Data sent to AmpX Portal API!");
        digitalWrite(LED_4_INTERNET, HIGH);
        digitalWrite(LED_5_SERVER, HIGH);
      } else {
        debug("❌ Error on sending POST: ");
        digitalWrite(LED_5_SERVER, LOW);
        debugln(httpResponseCode);
        debugln("Error message: " + http.errorToString(httpResponseCode));

        // Only test internet on connection-related errors
        if (httpResponseCode == HTTPC_ERROR_CONNECTION_REFUSED || 
            httpResponseCode == HTTPC_ERROR_CONNECTION_LOST ||
            httpResponseCode == HTTPC_ERROR_READ_TIMEOUT) {
              debugln("❌ No internet connection - this explains the API failure");
              digitalWrite(LED_4_INTERNET, LOW);
        } else {
          if (testInternetConnection()) {
            debugln("✅ Internet is working - API issue might be server-side");
            digitalWrite(LED_4_INTERNET, HIGH);
          } else {
            debugln("❌ No internet connection - this explains the API failure");
            digitalWrite(LED_4_INTERNET, LOW);
          }
        }
      }
      http.end();
    
    } else {
      debugln("WiFi Disconnected");
      digitalWrite(LED_4_INTERNET, LOW);
      digitalWrite(LED_5_SERVER, LOW);
    }
  }
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

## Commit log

2025-09-17 Added hardware and version
    [AmpX Open Energy Gateway.kicad_pcb, AmpX Open Energy Gateway.kicad_sch]
2025-09-18 updated schmatic, and pcb
    [AmpX Open Energy Gateway.kicad_pcb, AmpX Open Energy Gateway.kicad_sch]
2025-09-18 3D models working
    [AmpX Open Energy Gateway.kicad_pcb]
2025-09-22 feat: complete pcb design
    [AmpX Open Energy Gateway.kicad_pcb, AmpX Open Energy Gateway.kicad_sch, ESP32-DEVKITC-32U.step]
2025-09-23 Moved KiCad To version folder
    [AmpX Open Energy Gateway.kicad_pcb, AmpX Open Energy Gateway.kicad_sch]
2025-10-13 created gerbers
    [AmpX Open Energy Gateway-B_Cu.gbr, AmpX Open Energy Gateway-B_Mask.gbr, AmpX Open Energy Gateway-B_Paste.gbr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]
2025-10-14 Micheal changes
    [AmpX Open Energy Gateway.kicad_sch]
2025-10-16 feat: separate front and bottom pcbs
    [AmpX Open Energy Gateway-B_Cu.gbr, AmpX Open Energy Gateway-B_Mask.gbr, AmpX Open Energy Gateway-B_Paste.gbr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]
2025-10-17 increased meters to 5, fixed long connection bug of websockets
    [AmpX Open Energy Gateway-B_Cu.gbr, AmpX Open Energy Gateway-B_Mask.gbr, AmpX Open Energy Gateway-B_Paste.gbr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]
2025-11-01 added extra wire for ground
    [AmpX Open Energy Gateway.kicad_pcb, AmpX Open Energy Gateway.kicad_sch, Front.kicad_pcb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]
2026-03-31 api update
    [AmpX Open Energy Gateway.kicad_pcb, partitions.csv]
2026-08-10 Add shared API key support, OTA hardening, and Cloud Serverless prep docs.
    Bump firmware to 1.0.3 with X-AmpX-Api-Key on portal uploads; refresh Memory Bank and READMEs for OTA, auth, and InfluxDB Cloud Serverless next steps.
    [partitions.csv]
2026-08-18 Fix live HTTPS OTA watchdog crash and ship firmware 1.0.7.
    Use a static TLS client and a 16KB loop stack so Check for update no longer trips TG1WDT. Admin only fetches the manifest on button click, and version compare is numeric so older server builds are not offered as updates.
    [functions_ota.ino, functions_web.ino, open_energy_gateway.ino]
2026-08-22 Add Admin ship-mode Clear WiFi and bump firmware to 1.0.9.
    Erase stored WiFi before boxing a unit so customer first boot is AP setup; turn status LEDs off on reboot.
    [functions_web.ino, functions_wifi.ino, open_energy_gateway.ino]
2026-09-28 Keep one Modbus TCP socket open for each meter sweep.
    The page WebSocket stays up between registers and while a reply is still arriving, so Settings no longer stops after a few failed handshakes.
    [functions_ethernet.ino, functions_meter.ino, open_energy_gateway.ino]
2026-09-28 Add frequency and power-factor registers plus the S3 bring-up sketch.
    The Meatrol map now includes the registers the gateway already reads, and the bench sketch is kept with the firmware.
2026-09-28 Remove the Hardware tree from the firmware repository.
    Datasheets, KiCad projects, and gerbers are no longer in this working tree.
    [AmpX Open Energy Gateway-B_Cu.gbr, AmpX Open Energy Gateway-B_Mask.gbr, AmpX Open Energy Gateway-B_Paste.gbr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]
